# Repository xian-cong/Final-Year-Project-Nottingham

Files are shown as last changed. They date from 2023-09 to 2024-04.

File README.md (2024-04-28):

# WellnessAI+
## Overview of the Project
WellnessAI+ is an intelligent wearable device equipped with electrocardiogram (**ECG**) and advanced **AI** capabilities to offer a groundbreaking approach to **edge computing** to not only **predict heart disease** but also delve into the depths of **human emotions**. In this era of smart wearables, the integration of ECG with AI technology holds the potential to revolutionize the way we understand, monitor, and manage both our physical and emotional well-being. This dual-purpose capability signifies a pivotal leap forward in personalised healthcare and wellness management, ushering in a new era of preventative and predictive medicine.

### Code Directory
- [Obtain Sensor Readings](code/UART_ADC_DMA/CM4/Core/Src/main.c)
- [Emotion Recognition Model](ECG_Emotion_Recognition.ipynb)
- [Data Processing and Feature Extraction](data_preprocessing/printPickleData.py)
- [Running Real Time Inference with STM32MP157F-DK2 and ECG](code/EMOTION_AI/CM4/Core/Src/main.c)

### Demo
#### UI
UI Video (https://www.youtube.com/watch?v=PTiqgje0Kdc)
#### Performance
Demo Video (https://www.youtube.com/watch?v=h7NpJMywoSw)

### Features
- **ECG Monitoring**: The ECG sensor is used to measure the electrical activity of the heart and display the ECG waveform on the screen. The ECG waveform is also sent to the cloud for further analysis.
- **Heart Disease Prediction**: The ECG waveform is sent to the cloud for further analysis. The cloud will then predict the possibility of heart disease based on the ECG waveform. (Future Improvements)
- **Emotion Recognition**: The ECG waveform is sent to the edge for further analysis. The edge will then predict the real-time emotion of the user based on the ECG waveform.

### Design
| Front | Back | Inside | Side |
| :---: | :---: | :---: | :---: |
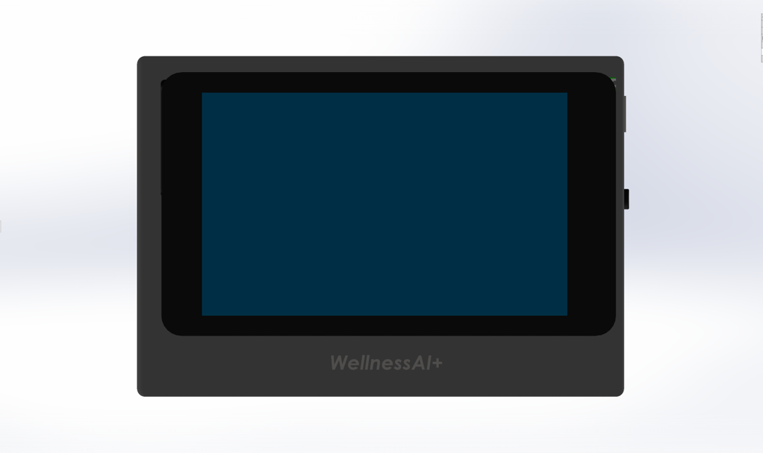
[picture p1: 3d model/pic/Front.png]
front
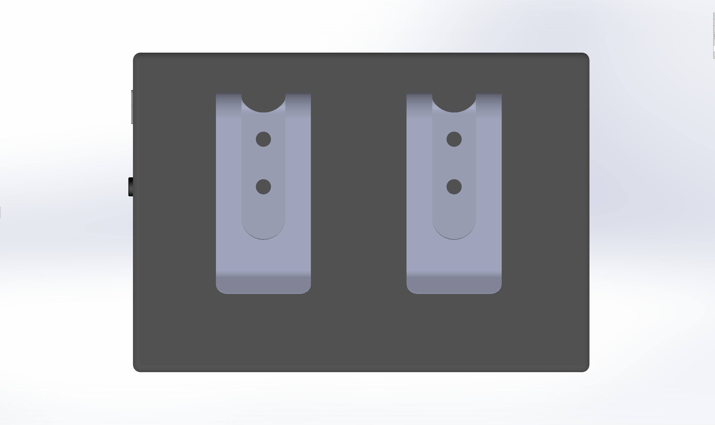
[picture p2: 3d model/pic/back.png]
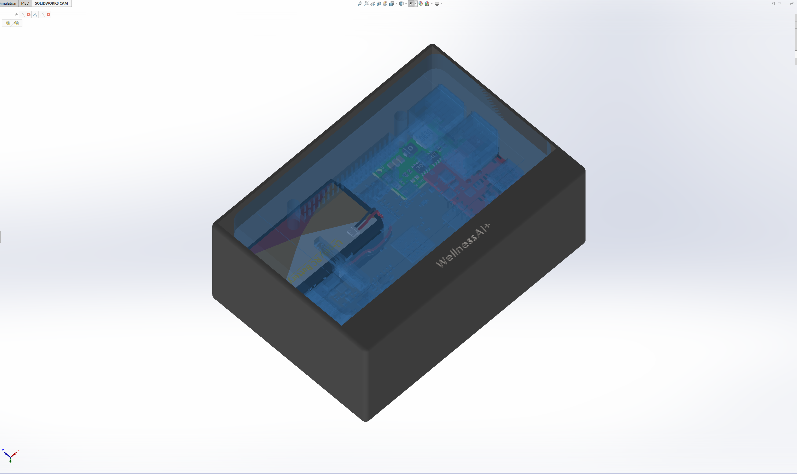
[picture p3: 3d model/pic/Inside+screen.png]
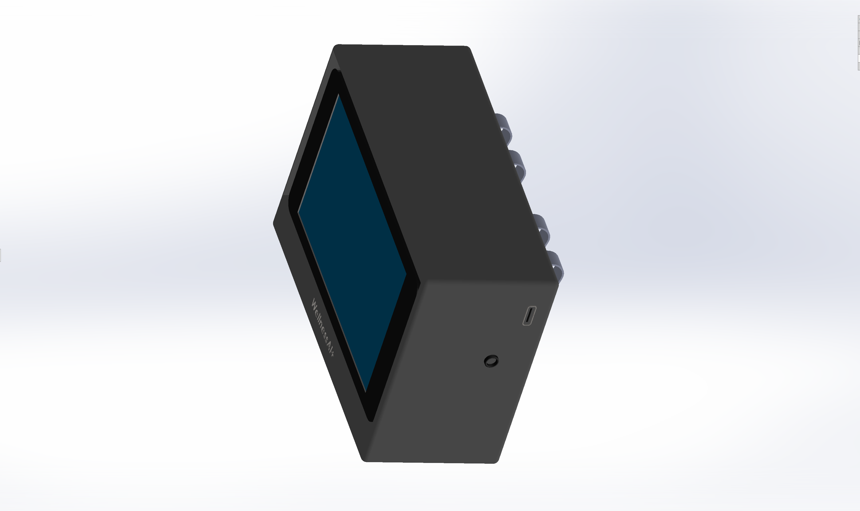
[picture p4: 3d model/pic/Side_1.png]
| |  |  |  

### Tools and Technologies Used
Block Diagram

## System Requirements
### Hardware
- STM32MP157F-DK2
- ECG Measurement Kit

### Software
- STM32CubeIDE (ver. 1.14.1)
- STM32 X-Cube-AI (ver. 8.1.0)
- Python

## Getting Started
### Clone Project
```
git clone https://github.com/xian-cong/Final-Year-Project-Nottingham.git
```

### Install Dependencies
```
pip install -r requirements.txt
```

### Run the Program
```
conda activate fyp_venv
python3 main.py
```

### Hardware Setup
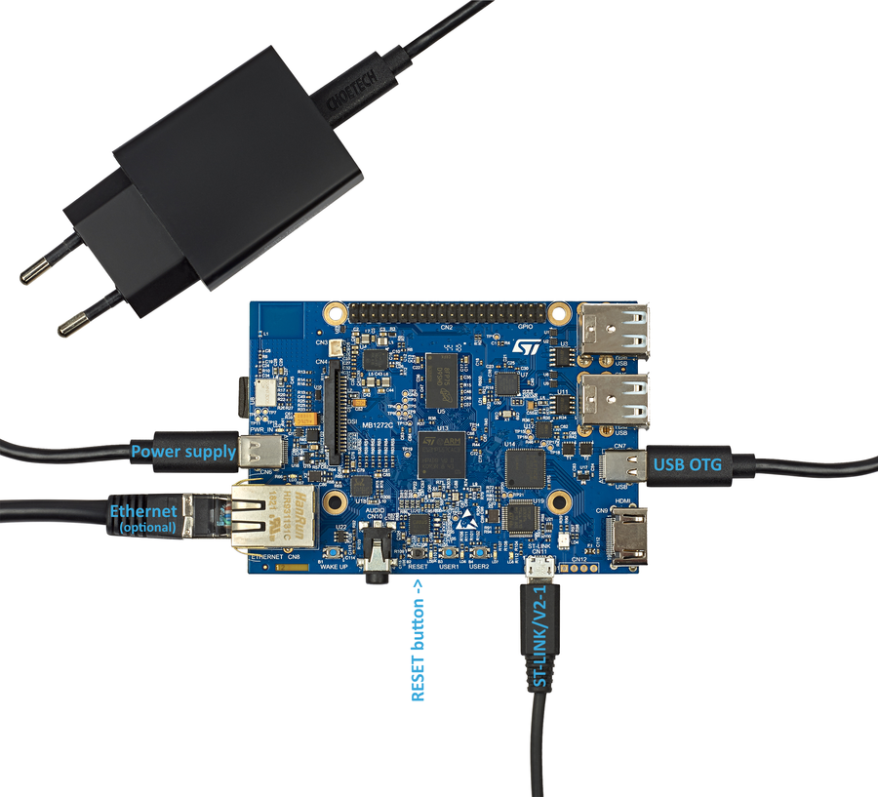
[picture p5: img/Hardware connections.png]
Hardware Setup


### Sensor Connection
Sensor Connection

## Time Management
### Gantt Chart
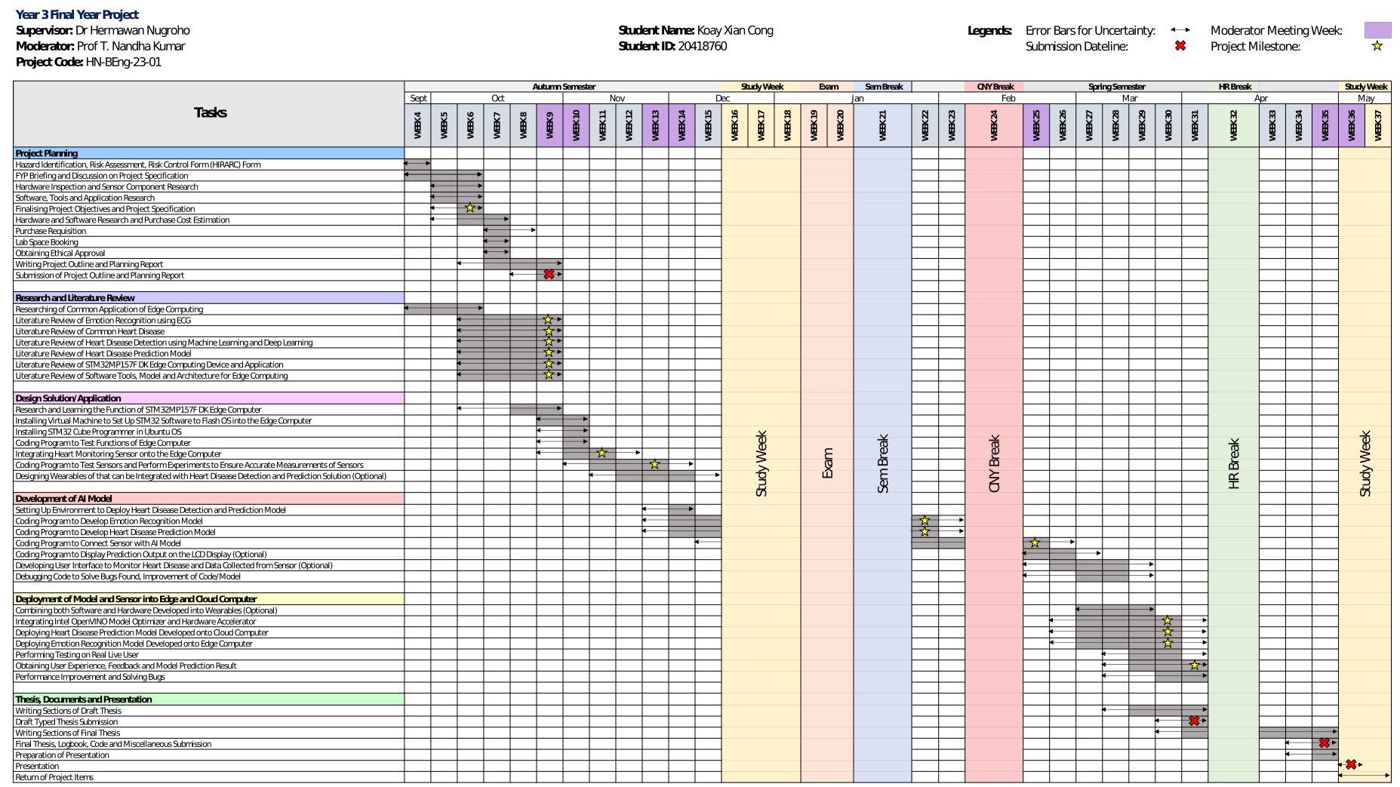
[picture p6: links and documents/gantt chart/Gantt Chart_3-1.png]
Gantt Chart


## Project Documentation
### Project Outline and Planning Report
[Project Proposal](links%20and%20documents/project%20outline%20and%20planning%20report/Project%20Outline%20and%20Planning%20Report.pdf)

### Project Specification
[Project Report](links%20and%20documents/FYP%20Project%20Specification.pdf)

### Project Thesis
[Project Thesis](links%20and%20documents/thesis/20418760%20-%20Koay%20Xian%20Cong%20-%20BEng%20FYP%20Final%20Thesis.pdf)

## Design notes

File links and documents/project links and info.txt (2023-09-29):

1. Intel OpenVino
https://www.intel.com/content/www/us/en/developer/tools/openvino-toolkit/overview.html
An open source toolkit that makes it easier to write once, deploy anywhere.

2. STM32
https://wiki.stmicroelectronics.cn/stm32mcu/wiki/AI:Introduction_to_Artificial_Intelligence_with_STM32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
Description for AI on the edge.

3. ARM Cortex-M
https://developer.arm.com/Architectures/M-Profile%20Architecture
Able to deploy AI using edge computing.

4. ARM Cortex-A
https://en.wikipedia.org/wiki/ARM_Cortex-A
Typical ways to deploy AI.

5. STM32 MPU
https://www.st.com/en/embedded-software/x-linux-ai.html
Able to run Tensorflow Lite and perform computer vision tasks.

6. STM32 Discovery Kit
https://www.st.com/en/evaluation-tools/stm32mp157c-dk2.html
Board that will be used.

7. Heart disease AI developed by previous year students.
https://link.springer.com/chapter/10.1007/978-981-19-3923-5_58
Thesis written.

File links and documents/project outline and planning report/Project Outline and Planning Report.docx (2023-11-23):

The University of Nottingham

Faculty of Engineering

Department of Electrical and Electronic Engineering

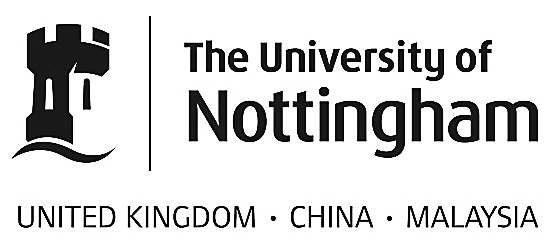
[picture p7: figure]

EEEE3026

Project Outline and Planning Report

WellnessAI+: Elevating Mental, Emotional and Physical Health with ECG-Enhanced Artificial intelligence

AUTHOR : KOAY XIAN CONG

ID : 20418760

SUPERVISOR : DR HERMAWAN NUGROHO

MODERATOR : PROF T. NANDHA KUMAR

DATE : 30th OCT 2023

Contents

# 1. Overview of the Project

Introduction

The focus of this project is to incorporate electrocardiogram (ECG) and artificial intelligence (AI) driven algorithms to offer a groundbreaking approach to edge computing to not only predict heart disease but also delve into the depths of human emotions. In this era of smart wearables, the integration of ECG with AI technology holds the potential to revolutionize the way we understand, monitor, and manage both our physical and emotional well-being. This dual-purpose capability signifies a pivotal leap forward in personalised healthcare and wellness management, ushering in a new era of preventative and predictive medicine. The deployment of AI into edge computers powered by ARM Cortex-M chips will also be further explored and discussed.

Problem Statement

Latterly, there has been growing acknowledgement of the significant impact that mental health has on the attainment of global development objectives, which has been illustrated by the incorporation of the Sustainable Development Goals. According to the World Health Organization (WHO), depression stands out as a major contributor to disability, while suicide ranks fourth leading cause of death among individuals aged 15 to 29. [1] Although there have been advancements made towards mental health issues, individuals dealing with mental health issues frequently encounter serious infringements of their human rights, discrimination, and social stigma. [1]

An electroencephalogram (EEG) is a commonly utilized tool to diagnose and measure the electrical activity in the brain. It involves the use of electrodes placed on the scalp to detect and monitor the brain’s electrical impulses and patterns of activity. The resulting data is typically displayed as a series of waveforms and is used to assess brain function, diagnose various neurological conditions, and study brain activity in research settings. EEGs are commonly employed in clinical medicine to aid in the diagnosis and management of conditions such as epilepsy, seizure disorders, emotions, stress levels, etc. Since EEG is a valuable tool, there are a lot of researchers incorporating EEG as a reliable tool to detect and recognize emotion. However, since EEG electrodes need to have good contact with the scalp to capture accurate brainwave data, achieving consistent and reliable contact with the scalp is difficult in a wearable form factor. Movements and shifts in the device, as well as hair interference, can affect the quality of EEG signals. EEG devices may be uncomfortable, inconvenient and expensive for regular use. [2]

Mental health aside, cardiovascular disease (CVDs) stands as the primary global cause of mortality, claiming around 17.9 million lives annually according to WHO. [3] More than 80% of CVD-related deaths result from heart attacks and strokes, with one-third occurring prematurely in individuals under 70 years of age. [3]

An electrocardiogram (ECG) can perform a simple test that records the electrical activity of the heart over a period. It is a widely used diagnostic tool to assess the heart’s rhythm and electrical conduction. The test is typically performed using electrodes placed on the skin’s surface at specific locations on the chest, arms, and legs. These electrodes detect the electrical signals generated by the heart as it beats and transmit the information to an ECG sensor, which then produces a visual representation of the heart’s electrical activity in the form of a graph or a series of waves. ECG can provide vital information about various aspects of cardiac health, including heart rate, the regularity of heartbeats, signs of abnormal rhythms, and the presence of certain heart conditions, such as ischemia or structural abnormalities. [4] Since ECG is a valuable tool used for diagnosing and monitoring heart-related issues and is commonly used in medical settings, there is a wide array of studies performed on enhancing ECG with Artificial Intelligence on heart disease analysis and prediction.

Background Information

Electrocardiogram (ECG)

An ECG is utilized as a medical test instrument that measures and records the electrical activity of the heart over a period. It provides medical professionals with several vital purposes such as diagnosing heart conditions, monitoring heart issues, etc. A sample signal of the ECG wave is shown in Figure 1. The P-wave represents the electrical signal when the atria contract and push blood into the ventricles. [5] The inter-beat interval (IBI) is used for detecting heart rate, which can be computed based on the distance between R peaks in the ECG waveforms. [6] The QRS complex shows the electrical activity when the ventricles contract to pump blood out to the body. [5] Finally, the T-wave is the recovery phase when the heart’s electrical system gets ready for the next beat. The standard placement of ECG is shown in Figure 2.

Autonomic Innervation of the Heart

According to Anatomy and Physiology 2, there are physiological interrelations between the heart and brain. [7] The autonomic innervation of the heart is a crucial part of the Autonomic Nervous System (ANS), which regulates involuntary bodily functions, including heart rate, blood pressure and respiratory rate. The regulation of heart rate is centred in the paired cardiovascular control centres within the medulla oblongata of the nervous system which are the sympathetic nervous system and the parasympathetic nervous system as shown in Figure 3. [7] While at rest, both centres offer subtle stimulation to the heart, contributing to the autonomic tone. The cardio accelerator triggers the release of the neurotransmitter norepinephrine, leading to a significant rise in heart rate, which takes place in both the sympathetic nervous system (SNS) and the sinoatrial (SA) node, while the cardioinhibitory release the neurotransmitter acetylcholine (Ach) into the parasympathetic nervous system (PNS). [7] The ANS would react based on the situation and alterations in the emotional experiences. For instance, a cardioaccelerator will be triggered in a “flight-or-fight” situation [8] whenever a person is in danger. Thus, when emotions are experienced, this interaction between the heart and brain can lead to certain changes or variations in how those emotions are felt or expressed. Hence, emotional experiences are not only influenced by our thoughts and feelings but also by the physiological interplay between heart and brain.

Arrhythmia

As discussed in the problem statement, CVDs contribute a significant amount of mortality. One of the approaches to detect arrhythmia is to use ECG. [9] Arrhythmia refers to an irregular or abnormal heartbeat. [10] The heart typically beats in a regular, rhythmic pattern to pump blood throughout the body which can be shown in the ECG waveform in Figure 1. In instances of arrhythmia, the heart can exhibit deviations in its rhythm, which may denote as excessive speed, rhythm or irregular pattern. [11] The severity of this condition varies, ranging from benign to life-threatening, depending on its specific type and its impact on an individual’s overall well-being. Arrhythmias may lead to symptoms such as palpitations, dizziness, breathlessness, or chest discomfort. [12] Thus, accurate diagnosis and monitoring of arrhythmias are essential to maintain good heart health.

Consumer Demand

To develop a wearable that can perform real-time emotion recognition on the edge as well as perform heart disease prediction on the cloud, the system needs to be accurate and lightweight. [5] Moreover, as stated in the problem statement, both mental and physical health contributed a significant amount of mortality based on statistics given by WHO. Based on a national survey performed in the US, roughly 30% of American adults make use of healthcare wearable devices. [13] Among these users, about 47.33% use these devices daily, and a significant majority, representing 82.38%, express their willingness to share the health data collected from these wearables with their healthcare providers, emphasizing the potential for healthcare professionals to access vital information for better-informed medical decisions. [13] Thus, based on the potential number of users available, it reveals a compelling case for the development and commercialization of healthcare wearables which ultimately enhance the overall quality of healthcare services.

Aim

The objective of this project is to create a health monitoring system that integrates an ECG measurement kit with an STM32 edge computer and a cloud-based computer. This system comprises two key components: a model for predicting heart disease (cloud computer) and another for real-time emotion recognition (edge computer). The most important goal is to design a circuit that captures bioelectric signals from the heart accurately. Next, a data processing method to acquire features with physiological and physical significance needs to be designed. [2] This innovative approach allows users to not only track their physical health but also their mental well-being. Additionally, the project explores the utilization of Intel OpenVINO as a model optimizer and hardware accelerator, facilitating the deployment of AI models without the need to modify the underlying code. The model for real-time emotion recognition needs to be lightweight enough to be embedded into a device to implement edge computing. [2] [5]

This project holds significant importance in the realm of healthcare technology. Combining ECG measurement with advanced AI models, it offers a holistic approach to health monitoring, addressing both physical and emotional aspects. The ability to predict heart disease can lead to early intervention and potentially life-saving measures. Real-time emotion recognition can aid in mental health support, especially in times when stress and emotional well-being are increasingly critical. The use of Intel OpenVINO streamlines the deployment of AI models, making this technology more accessible and adaptable for a wide range of applications.

Block Diagram

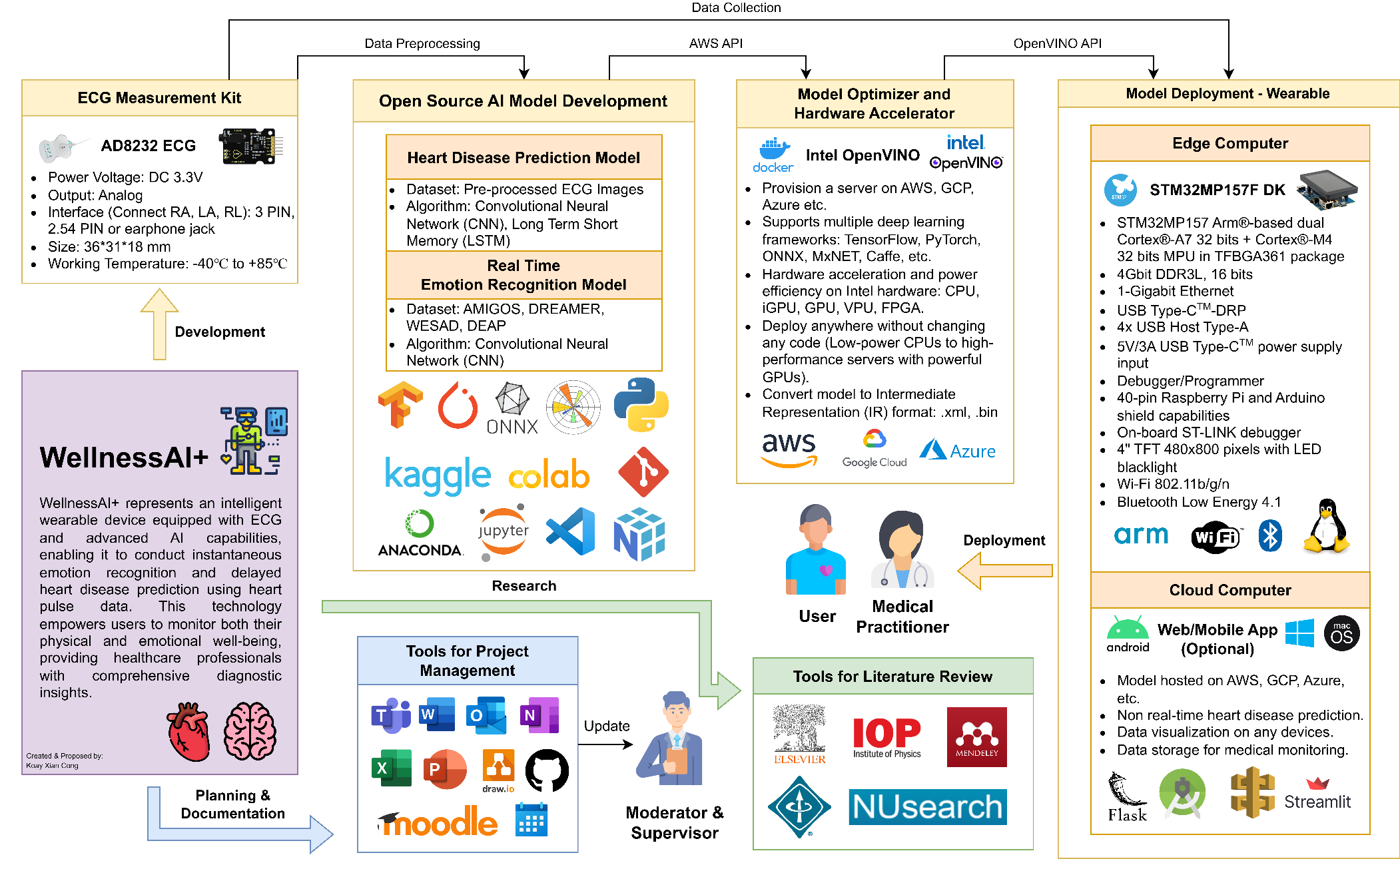
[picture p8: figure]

# 2. Specification

Hardware

Requirements: Setting up STM32MP157F DK edge computer.

Priority: High

Standards & Practices: Follow the manufacturer’s guidelines or hardware setup and ensure electrical safety protocols. [14]

Tests:

1. Conduct a power-on test.
2. Validate hardware connections.
3. Verify the functionality of essential components.

Success Measure: Successful boot-up and initialization of STM32MP157F DK with no hardware and electrical issues.

Attainability and Achievability: Achievable with the necessary resources and adherence to the manufacturer's instructions. [14]

Requirements: Integrating ECG measurement kit onto edge computer.

Priority: High

Standards & Practices: Ensure secure and accurate data transmission, and compliance with medical data protection standards.

Tests:

1. Verify data connection between the ECG kit and edge computer.
2. Confirm data accuracy.

Success Measure: Successful integration with consistent, accurate ECG data transmission.

Attainability and Achievability: Achievable with appropriate hardware interfaces and software development.

Requirements: Create a real-life model of the wearable designed to integrate both software and hardware onto it.

Priority: Low (Stretch goal)

Standards & Practices: Utilize ergonomic design to ensure user comfort and safety.

Tests:

1. Conduct usability tests with potential users.
2. Assess integration of hardware and software components into the wearables.

Success Measure: Positive feedback from users on functionality and design.

Attainability and Achievability: Challenging but attainable as a stretch goal, may require additional resources and time.

Software

Requirements: Setting up applications and tools for software development.

Priority: High

Standards, Practices and Licenses: Follow industry best practices, and adhere to software development guidelines and licensing agreements. Use open-source tools and software.

Tests:

1. Ensure proper installation of development tools.
2. Run initial tests to confirm they function as intended.

Success Measure: Successful setup of software development environment without any critical issues.

Attainability and Achievability: Achievable with the necessary software and resources.

Requirements: Coding program to familiarize and test functions of edge computer and ECG.

Priority: Medium

Standards, Practices and Licenses: Adhere to coding and programming best practices, ensure modularity and standardization of code, and follow any relevant licenses for code libraries. Use open-source libraries.

Tests:

1. Run test cases to confirm the functionality of the edge computer and ECG components.

Success Measure: Successful development of a program that effectively tests and familiarizes with edge computer and ECG.

Attainability and Achievability: Achievable with the necessary programming skills and resources.

Requirements: Coding program to test ECG sensor.

Priority: Medium

Standards, Practices and Licenses: Adhere to coding and programming best practices, ensure modularity and standardization of code, and follow any relevant licenses for code libraries. Use open-source libraries.

Tests:

1. Conduct tests and experiments to verify the accuracy and reliability of ECG sensor data.

Success Measure: A program that effectively tests the ECG sensor and provides reliable data.

Attainability and Achievability: Achievable with the necessary programming skills and resources.

Requirements: Designing wearables to integrate edge computer and ECG sensors.

Priority: Low (Stretch goal)

Standards, Practices and Licenses: Follow wearable design best practices, and consider safety and user comfort.

Tests:

1. Conduct usability tests with potential users.
2. Assess integration of hardware and software components into the wearable.

Success Measure: Positive feedback on the design and functionality of the integrated wearable.

Attainability and Achievability: Challenging but attainable as a stretch goal, may require additional design and engineering resources.

Requirements: Coding program to create and test heart disease prediction model.

Priority: High

Standards, Practices and Licenses: Adhere to coding and programming best practices, ensure modularity and standardization of code, and follow any relevant licenses for code libraries. Use open-source libraries and datasets.

Tests:

1. Conduct tests to verify the accuracy and effectiveness of the heart disease prediction model.

Success Measure: A functional program that successfully creates and tests the heart disease prediction model.

Attainability and Achievability: Achievable with the necessary programming skills and resources.

Requirements: Coding program to create and test emotion recognition model.

Priority: High

Standards, Practices and Licenses: Adhere to coding and programming best practices, ensure modularity and standardization of code, and follow any relevant licenses for code libraries. Use open-source libraries and datasets.

Tests:

1. Conduct tests to verify the accuracy and effectiveness of the emotion recognition model.

Success Measure: A functional program that successfully creates and tests the emotion recognition model.

Attainability and Achievability: Achievable with the necessary programming skills and resources.

Requirements: Implementing Intel OpenVINO as a model optimizer and hardware accelerator.

Priority: Medium

Standards, Practices and Licenses: Follow the manufacturer’s guidelines, and comply with relevant licensing agreements.

Tests:

1. Validate the performance improvement achieved through OpenVINO optimization.

Success Measure: Successful integration and performance improvement using Intel OpenVINO.

Attainability and Achievability: Achievable with access to OpenVINO resources and appropriate hardware.

Requirements: Setting up and deployment of heart disease prediction model in cloud computer.

Priority: Medium

Standards, Practices and Licenses: Ensure cloud deployment adheres to security and privacy standards and complies with licensing agreements.

Tests:

1. Validate the successful deployment and functioning of the heart disease prediction model in the cloud.

Success Measure: Successful deployment of the model in the cloud environment with proper functionality.

Attainability and Achievability: Achievable with access to cloud computing resources and expertise.

Requirements: Deployment of emotion recognition model in edge computer.

Priority: Medium

Standards, Practices and Licenses: Ensure compliance with edge computing best practices and relevant licenses.

Tests:

1. Confirm that the emotion recognition model works effectively on the edge computer.

Success Measure: Successful deployment of the model on the edge device with proper functionality.

Attainability and Achievability: Achievable with the necessary edge computing resources and expertise.

Requirements: Coding program to display data collected from sensor and model output result.

Priority: Low (Stretch goal)

Standards, Practices and Licenses: Follow best practices for data visualization and ensure compliance with relevant licenses. Use open-source libraries.

Tests:

1. Validate the program’s ability to display sensor data and model output results effectively.

Success Measure: Development of a program that successfully displays sensor data and model output results.

Attainability and Achievability: Achievable as a stretch goal, may require additional software development resources.

# 3. Methodology

Step 1: Setting up software and hardware for STM32MP157F-DK2.

Relevant tools, Justification & Limitations:

1. STM32MP157F-DK2. [14]
- Powerful hardware: Powered by a dual-core ARM Cortex-A7 CPU with an ARM Cortex-M4 microcontroller, it is power-efficient and suitable for real-time tasks.
- Power efficiency: STM32MP1 microprocessors are designed for low power consumption, making them well-suited for battery-powered or wearable devices.
- Real-time capabilities: The presence of an ARM Cortex-M4 microcontroller on the edge computer allows for real-time control and signal processing, which can be crucial for the deployment of real-time emotion recognition.
- Customization: Comes with a 4” TFT 480x800 pixels with LED backlight, allowing data collected and model output to be displayed.

Limitations:

- Compared to Raspberry Pi, STM32MP157F-DK2 has fewer readily available resources and support due to smaller communities.
- STM32MP157D-DK2 is less common and requires sourcing from specific distributors.
2. VirtualBox to run Ubuntu OS.
- Compatibility: The STM32 Cube Programmer has better compatibility with a Linux environment since the documentation given is in Ubuntu OS. This ensures that it functions smoothly without any compatibility issues.

Limitations:

- Virtualization introduces overhead, which can impact the overall performance of running STM32 Cube Programmer and other applications.
- USB passthrough may not work seamlessly with all STM32 devices or programming and debugging tools.
- The STM32 Cube Programmer relies on USB drivers and hardware communication. Virtualized environments can sometimes be less compatible with specialized drivers, leading to connectivity and communication problems with STM32 devices.
3. STM32 Cube programmer. [14]
- Official tool by STMicroelectronics: STM32 Cube Programmer is developed and maintained by the manufacturer, ensuring compatibility and reliability.
- Integrated Development Environment: STM32 Cube Programmer is part of the STM32Cube ecosystem, which provides a comprehensive set of development tools for STM32 microcontrollers and microprocessors. It integrates well with other STM32Cube tools and libraries, streamlining the development process.
- Programming and debugging: It offers a user-friendly interface for programming STM32 devices, which can include flashing firmware, configuring settings, memory management, and debugging applications.

Limitations:

- STM32 Cube Programmer can be resource-intensive, particularly when working with large projects.

Potential Additional Tasks: Familiarize with Ubuntu OS and STM32 Cube programmer.

Step 2: Integrating ECG kit onto edge computer.

Relevant tools, Justification & Limitations:

1. AD8232 ECG measurement kit. [15]
- Data collection: The ECG measurement kit is chosen for its accuracy and precision in collecting vital heart activity.

Limitations:

- Ensuring seamless compatibility between the ECG kit into the edge computer may be technically challenging and may require expertise in hardware interfacing.
- Wearable ECG sensors may not be as comfortable for long-term use, potentially affecting user adoption and compliance.

Potential Additional Tasks:

- Perform tests and experiments to verify that the ECG kit is functioning correctly and can collect ECG data accurately.
- Implementation of data transmission protocols to ensure that ECG data collected by the kit can be transmitted to the edge computer in real time.

Step 3: Open-Source AI Model Development.

Relevant tools, Justification & Limitations:

1. Python and machine learning (ML)/deep learning (DL) libraries (NumPy, Matplotlib, etc.).
- Open source: Python is a widely used programming language for ML and DL. It has various libraries available for data manipulation, analysis, visualization, etc in AI model development.

Limitations:

- Advanced DL models may require substantial computational resources, which could impact performance on resource-constraints systems.
2. Anaconda/Google Colab.
- Local training: Anaconda provides a convenient environment for managing Python packages and creating isolated development environments. Since there are 2 models developed: heart disease prediction and emotion recognition, this feature ensures package compatibility between projects.
- Cloud training: Google Colab is a cloud-based platform that offers free GPU and TPU resources for training DL models, reducing the need for computational power.

Limitations:

- The availability of free resources on Google Colab may be limited, and reliance on cloud-based resources may have data privacy and internet connectivity considerations. Running DL models locally requires a lot of computational power and time.
3. Deep learning libraries (TensorFlow/PyTorch, etc.).
- Pre-built neural network architectures: Enabling AI model development more accessible and efficient with optimization tools and GPU acceleration available.

Limitations:

- Implementing complex neural network architecture requires expertise in DL, and training large models may demand significant computational resources.
4. Git/GitHub.
- Efficient: Version control system that allows for efficient version tracking in AI model development.

Limitations:

- Managing large datasets or models within Git repositories can be challenging, and it’s important to follow best practices to avoid repository bloat.

Potential Additional Tasks:

- Familiarize with software tools and DL models.
- Perform data preprocessing, which may involve tasks like data augmentation, normalization, and feature extraction, to prepare the input data for the AI model.
- Retrain model available online to validate the accuracy and performance of the model.

Step 4: Model Optimizer and Hardware Accelerator.

Relevant tools, Justification & Limitations:

1. Intel OpenVINO Toolkit.
- Compatibility: Supports multiple DL frameworks (TensorFlow, PyTorch, etc.).
- Performance: Enhance the performance and efficiency of AI models, allowing them to run seamlessly on Intel-based hardware.
- Code reusability: Deploy anywhere without changing any code.

Limitations:

- Depending on the complexity of the AI models and the specific hardware accelerators used, there may be some steep learning curve and resource req to effectively utilize the Intel OpenVINO Toolkit.

Additional Tasks:

- Familiarize with Intel OpenVINO Toolkit.
- Configure and optimize AI models using the Intel OpenVINO Toolkit for deployment on the STM32MP57F-DK2 hardware accelerator and assess the performance improvements achieved through model optimization.

Step 5: Deployment of AI models into edge computers and cloud computers.

Relevant tools, Justification & Limitations:

1. Edge Computer (STM32MP157F).
- As discussed above.
2. Cloud Computer (AWS, Azure, GCP).
- Scalable resources: Cloud platforms offer scalable compute resources, allowing for the deployment of large and complex AI models.
- High-performance GPU: Cloud providers often offer access to powerful GPU instances, which can significantly accelerate AI model inference and training.
- Deployment into Web/Mobile apps: Cloud providers offer APIs to link the results onto frontend web/mobile apps.

Limitations:

- AI models deployed in the cloud may experience network latency, which can be a concern for real-time applications.
- AI models deployed in the cloud may experience network latency, which can be a concern for real-time applications.

Potential Additional Tasks:

- Ensure that the AI models are optimized for deployment on both the edge computer and the cloud platform.

# 4. Risk Management and Mitigations

Step 1: Setting up software and hardware for STM32MP157F-DK2.

1. Risk: Limited Community Support: Difficult to get support when issues arise.

Mitigation: Establish direct contact with STM32MP157F-DK2 user forums, seek expert advice, and build a network of contacts for troubleshooting.

Impact: Limited community support may result in longer issue resolution times.

Likelihood: Medium

2. Risk: Hardware Compatibility: Incompatibility issues between the STM32MP157F-DK2 and the ECG measurement kit may arise.

Mitigation: Prior to integration, perform compatibility testing, and refer to hardware documentation.

Impact: Delay in project timeline.

Likelihood: Low

3. Risk: Human error: Short circuit due to incorrect power connections.

Mitigation: Supply power and connect peripherals to the edge computer by adhering to the documentation and requirements.

Impact: Delay in project timeline if new microcontroller order is needed.

Likelihood: Low

Step 2: Integrating ECG kit onto edge computer.

1. Risk: Health and safety issue: ECG sensor being tested on real-life human needs to adhere to health and safety compliance.

Mitigation: The subject’s skin needs to be wiped with alcohol before snap on electrode is applied. [2]

Impact: Health and safety issues can lead to ethical and legal concerns, project delays, and potential health risks to human subjects.

Likelihood: High

Step 3: Open-Source AI Model Development

1. Risk: Computational Resources: Advanced deep learning models may require substantial computational resources, impacting project performance on resource-constrained systems.

Mitigation: Optimize and simplify AI models, employ cloud-based resources when necessary, and manage hardware efficiently.

Impact: Delayed model training, and performance degradation.

Likelihood: High

2. Risk: Data Privacy: Reliance on cloud-based resources may raise security concerns.

Mitigation: Implement data encryption, access control, and ensure compliance with data protection regulations. Use open-source datasets.

Impact: Data breaches, legal liabilities.

Likelihood: High

3. Risk: Model detection: An exclusive reliance on deep learning methods proved insufficient in identifying all crucial ECG signal features. [5] [11]

Mitigation: Hybrid strategy is applied to improve detection efficiency. [5]

Impact: Inefficient model detection can lead to inaccurate results and potentially harmful misdiagnoses.

Likelihood: High

4. Risk: Dataset Requirement: ECG signal analysis demands a substantial volume of data for accurate results, increasing the risk of misdiagnosing specific heart conditions. [11]

Mitigation: Adequately address data volume requirements by ensuring the dataset size is sufficient for the AI models' training and validation processes. Performing data augmentation to increase the size of the dataset available.

Impact: Inadequate data volume can lead to misdiagnoses and reduce the AI model's effectiveness.

Likelihood: High

5. Risk: Dataset Availability: Discovering a comprehensive framework with corresponding standards accessible to the general population is a complex task. [11]

Mitigation: Explore various sources, including open-source datasets to gather a diverse and representative ECG dataset. Ensure compliance with data protection regulations.

Impact: Limited or inadequate dataset availability can hinder AI model development and testing.

Likelihood: High

6. Risk: Human factors: Age, gender, physical health, and lifestyle exert an influence on the amplitude and duration of individuals' ECG readings. [11]

Mitigation: Focus on a specific group of users and reduce the range of demographic groups.

Impact: Failure to account for human factors can lead to biased or unreliable AI models.

Likelihood: Medium

7. Risk: Wearable deployments: Physical activity, such as running, walking, and sleeping can affect the ECG signal’s morphology, contributing to signal noise. [11]

Mitigation: Develop noise-filtering algorithms and signal-preprocessing techniques to enhance the quality of ECG data collected from wearable devices.

Impact: Failure to address signal noise can lead to inaccurate ECG signal analysis.

Likelihood: Medium

Step 4: Model Optimizer and Hardware Accelerator

1. Risk: Learning Curve: Utilizing the Intel OpenVINO Toolkit effectively may require a steep learning curve.

Mitigation: Invest time in training and tutorials, seek expert assistance, and start with smaller, well-documented models.

Impact: Delays in model optimization, increased development time.

Likelihood: Medium

2. Risk: Resource Requirements: Depending on the complexity of AI models and the specific hardware accelerators used, resource requirements may be higher than anticipated.

Mitigation: Conduct thorough resource planning, allocate sufficient resources, and monitor utilization.

Impact: Performance bottlenecks, potential project overruns.

Likelihood: Medium

Step 5: Deployment of AI models into edge computer and cloud computer

1. Risk: Real-Time Edge Deployment Challenges: The model takes too long to produce output.

Mitigation: Rigorously test AI model deployment on the STM32MP157F-DK2 to ensure real-time performance and functionality.

Impact: Real-time deployment issues can lead to model inaccuracies and reduced usability.

Likelihood: High

2. Risk: API and Compatibility Challenges: AI models developed are difficult to implement into edge and cloud computers due to API and compatibility issues.

Mitigation: Perform test cases with available AI models before training a new model.

Impact: Delay in project timeline.

Likelihood: High

3. Risk: Network Latency: AI models deployed in the cloud may experience network latency.

Mitigation: Optimize model size, employ edge computing where possible, and implement network performance enhancements.

Impact: Delayed response times.

Likelihood: Medium

4. Risk: User comfort in wearable deployments: Wearable ECG sensors may not be comfortable for extended use, potentially impacting user compliance.

Mitigation: Conduct user testing, gather feedback, and refine the design to enhance user comfort.

Impact: Reduced user adoption, less reliable data.

Likelihood: Medium

5. Risk: Cost Overruns: Cloud-based deployment can incur unexpected costs, especially for resource-intensive AI models.

Mitigation: Implement cost monitoring and budgeting, choose cost-efficient configurations, and regularly review usage.

Impact: Exceeding budget, financial strain.

Likelihood: Low

# 5. Time Plan

The Gantt Chart for time planning has been structured considering the interdependencies between tasks. It consists of six primary tasks scheduled chronologically, which include:

1. Project planning,
2. Research and literature review,
3. Design solutions/applications,
4. Development of AI model,
5. Deployment of model and sensor into edge and cloud computer,
6. Thesis, documents and presentation.

Within the "Design solutions/applications" phase, there's a requirement to set up and test ECG sensors, STM32MP157F, and software. This precedes the design of the model architecture before moving on to the development of the AI model. The deployment of the model and sensor hinges on the completion of the AI model, so it follows this phase.

To ensure tasks stay on track, there are project milestones marked at various points, and four progress reviews are scheduled:

1. Moderator Review 1 (Week 9 – Week 10):
- Finalising Project Objectives and Project Specifications.
- Research and literature review.
2. Moderator Review 2 (Week 13 – Week 14):
- Coding program to test functions of edge computer.
- Coding program to test sensors and perform experiments to ensure accurate measurements of sensors.
3. Moderator Review 3 (Week 25):
- Coding program to develop emotion recognition model.
- Coding program to develop heart disease prediction model.
- Coding program to connect sensor with AI model.
4. Moderator Review 4 (Week 35 – Week 36):
- Integrating Intel OpenVINO model optimizer and hardware accelerator.
- Deploying heart disease prediction model developed onto cloud computer.
- Deploying emotion recognition model developed onto edge computer.
- Obtaining user experience, feedback and model prediction results.

In light of the potential risks and issues mentioned earlier, a parallelization technique is applied to enable the execution of multiple tasks simultaneously, particularly those that are independent of one another.

Additionally, provisions have been made for debugging codes and addressing bugs that may surface during model development and user testing. Improvements can be made based on feedback obtained from users.

The Gantt chart also incorporates error bars to account for uncertainties. In cases where previously unidentified risks arise, these error bars provide additional time to mitigate the issues.

Lastly, the Gantt chart includes optional and supplementary tasks, described as stretch goals, which can be pursued if there is available time before each progress review.

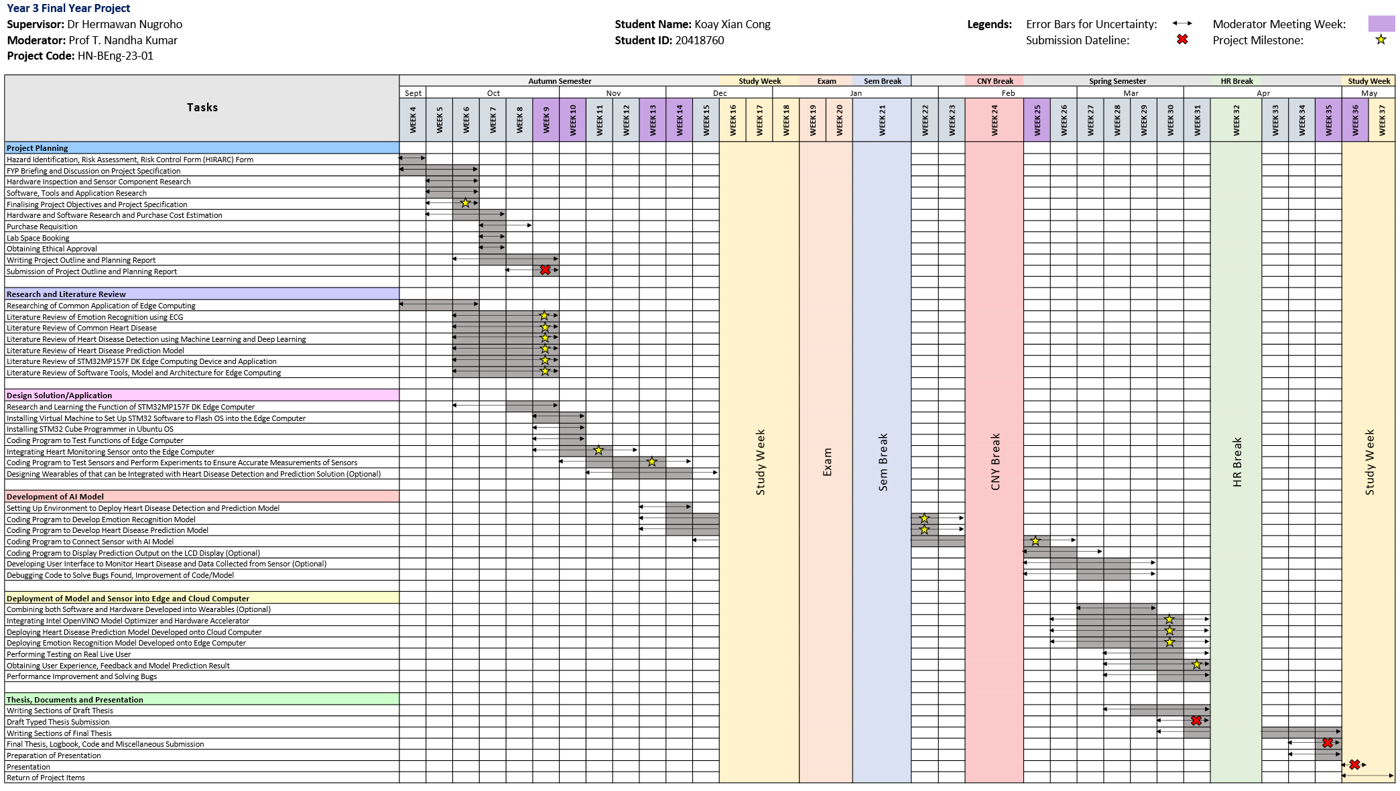
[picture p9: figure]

Gantt Chart

# 6. References

[1] “Mental health.” Accessed: Oct. 19, 2023. [Online]. Available: https://www.who.int/health-topics/mental-health#tab=tab_1

[2] X. Wang, J. Zhang, C. He, H. Wu, and L. Cheng, “A Novel Emotion Recognition Method Based on the Feature Fusion of Single-Lead EEG and ECG Signals,” IEEE Internet Things J, 2023, doi: 10.1109/JIOT.2023.3320269.

[3] “Cardiovascular diseases.” Accessed: Oct. 19, 2023. [Online]. Available: https://www.who.int/health-topics/cardiovascular-diseases#tab=tab_1

[4] Ed Burns and Mike Cadogan, “Myocardial Ischaemia • LITFL • ECG Library Diagnosis.” Accessed: Oct. 19, 2023. [Online]. Available: https://litfl.com/myocardial-ischaemia-ecg-library/

[5] A. L. Golande and T. Pavankumar, “Optical electrocardiogram based heart disease prediction using hybrid deep learning,” J Big Data, vol. 10, no. 1, pp. 139–13, 2023, doi: 10.1186/s40537-023-00820-6.

[6] A. Tjolleng et al., “Classification of a Driver’s cognitive workload levels using artificial neural network on ECG signals,” Appl Ergon, vol. 59, no. Pt A, pp. 326–332, 2017, doi: 10.1016/j.apergo.2016.09.013.

[7] J. G. Betts et al., Anatomy & Physiology -OpenStax. 2013.

[8] P. J. Bota, C. Wang, A. L. N. Fred, and H. Placido Da Silva, “A Review, Current Challenges, and Future Possibilities on Emotion Recognition Using Machine Learning and Physiological Signals,” IEEE access, vol. 7, pp. 140990–141020, 2019, doi: 10.1109/ACCESS.2019.2944001.

[9] H. Yang and Z. Wei, “Arrhythmia Recognition and Classification Using Combined Parametric and Visual Pattern Features of ECG Morphology,” IEEE Access, vol. 8, 2020, doi: 10.1109/ACCESS.2020.2979256.

[10] K. Subramanian and N. K. Prakash, “Machine learning based cardiac arrhythmia detection from ECG signal,” in Proceedings of the 3rd International Conference on Smart Systems and Inventive Technology, ICSSIT 2020, 2020. doi: 10.1109/ICSSIT48917.2020.9214077.

[11] T. Padma, A. Uday Kiran, C. Jahnavi, S. Rahul, N. Raja, and M. Kamal Kumar, “Detection and Classification of Arrhythmias by Deploying Deep Learning Models,” in Journal of Physics: Conference Series, 2022. doi: 10.1088/1742-6596/2325/1/012053.

[12] A. A. Salman and A. Ibarahim, “Detection of Cardiac Arrhythmias in Electroc Ardiograms Using Deep Learning,” in ISMSIT 2022 - 6th International Symposium on Multidisciplinary Studies and Innovative Technologies, Proceedings, 2022. doi: 10.1109/ISMSIT56059.2022.9932742.

[13] R. Chandrasekaran, V. Katthula, and E. Moustakas, “Patterns of Use and Key Predictors for the Use of Wearable Health Care Devices by US Adults: Insights from a National Survey,” Journal of Medical Internet Research, vol. 22, no. 10. 2020. doi: 10.2196/22443.

[14] “Unpack the STM32MP157x-DK2 board - stm32mpu.” Accessed: Oct. 22, 2023. [Online]. Available: https://wiki.st.com/stm32mpu/wiki/Getting_started/STM32MP1_boards/STM32MP157x-DK2/Let%27s_start/Unpack_the_STM32MP157x-DK2_board

[15] “Ks0261 keyestudio AD8232 ECG Measurement Heart Monitor Sensor Module - Keyestudio Wiki.” Accessed: Oct. 22, 2023. [Online]. Available: https://wiki.keyestudio.com/Ks0261_keyestudio_AD8232_ECG_Measurement_Heart_Monitor_Sensor_Module#Test_Result

[16] J. Gordon Betts et al., Anatomy and Physiology 2e. Houston, Texas: OpenStax, 2022.

# 7. Appendix

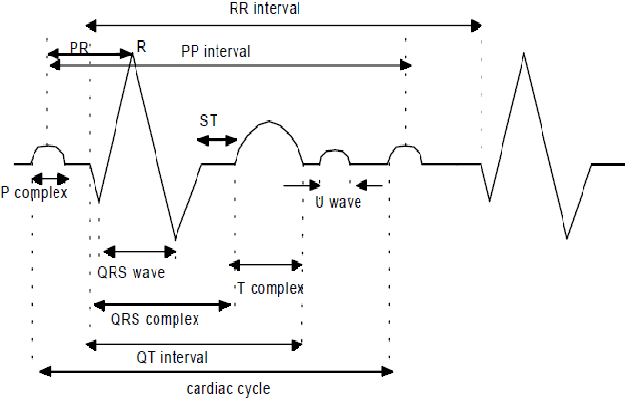
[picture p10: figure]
Figure 1 from Fig : A cardiac cycle of an ECG Classification of Arrhythmia | Semantic Scholar

Figure 1. EEG cycle.

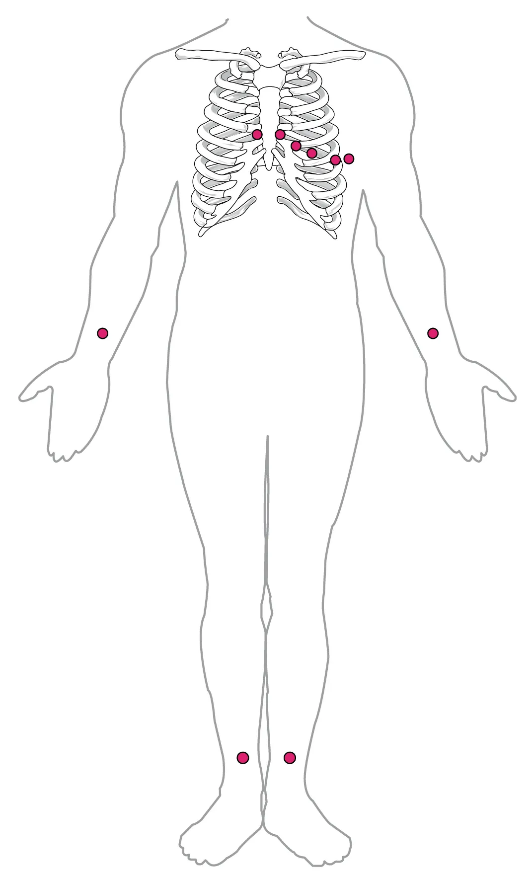
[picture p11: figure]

Figure 2. Standard placement of ECG. [16]

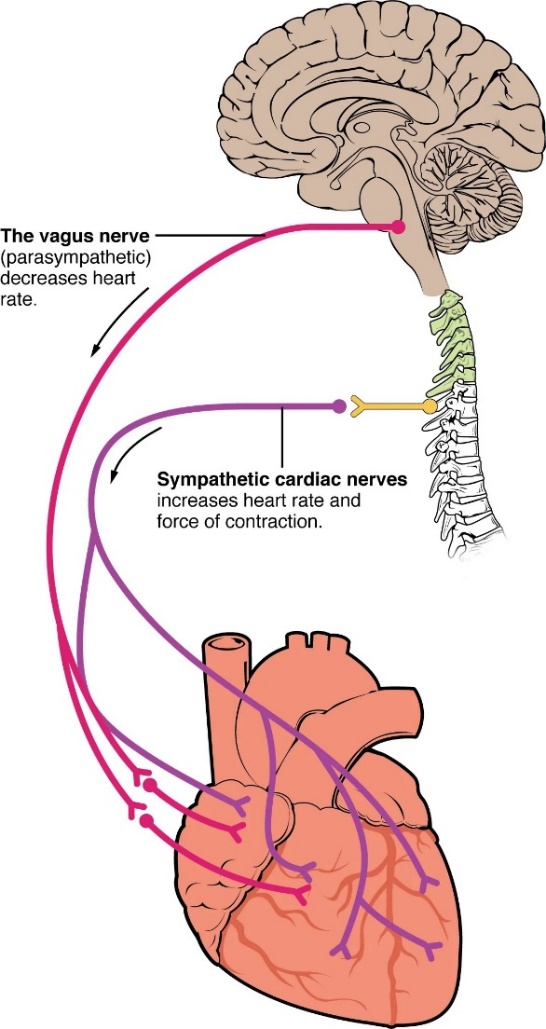
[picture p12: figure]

Figure 3. Autonomic Innervation of the Heart.

Project Specifications

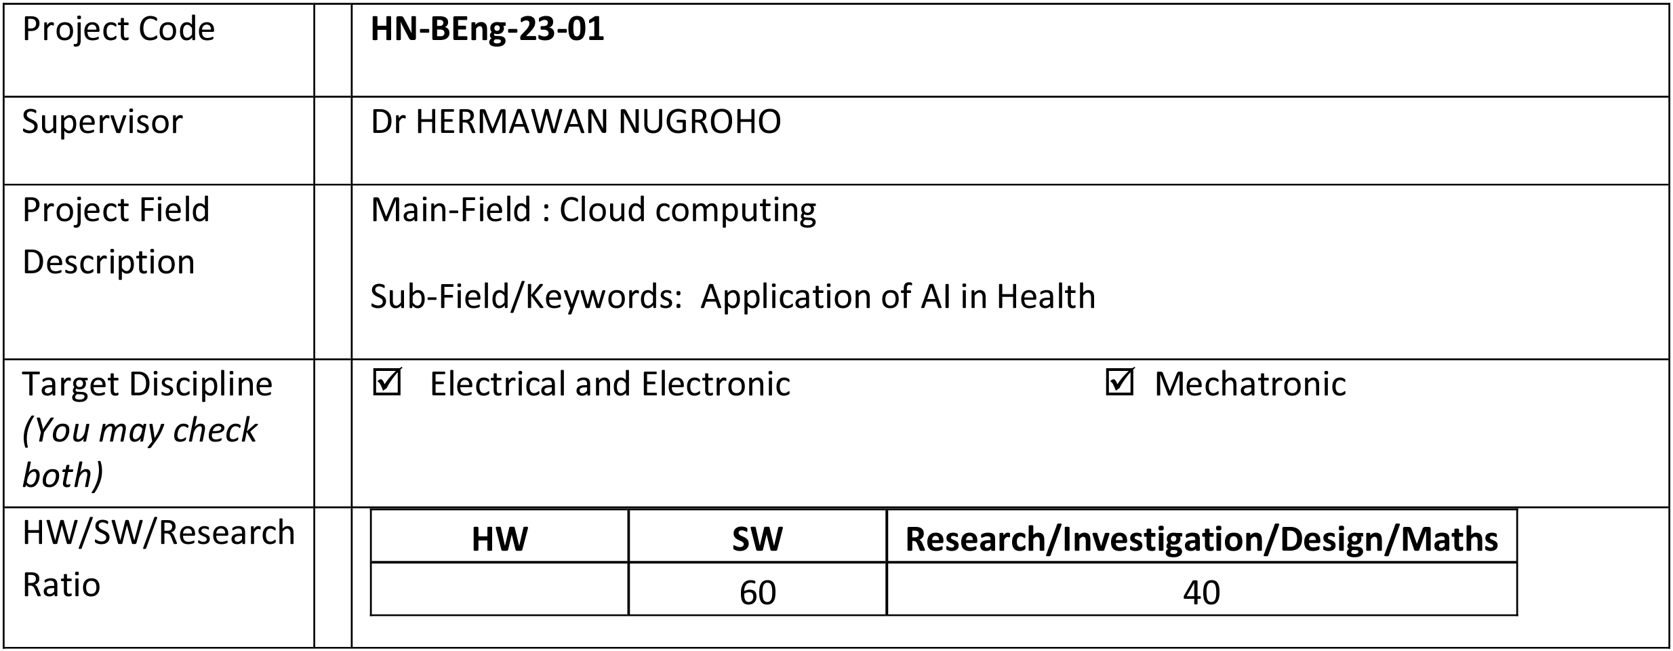
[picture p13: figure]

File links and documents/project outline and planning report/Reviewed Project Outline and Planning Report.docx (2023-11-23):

The University of Nottingham

Faculty of Engineering

Department of Electrical and Electronic Engineering


EEEE3026

Project Outline and Planning Report

WellnessAI+: Elevating Mental, Emotional and Physical Health with ECG-Enhanced Artificial intelligence

AUTHOR : KOAY XIAN CONG

ID : 20418760

SUPERVISOR : DR HERMAWAN NUGROHO

MODERATOR : PROF T. NANDHA KUMAR

DATE : 30th OCT 2023

Contents

# 1. Overview of the Project

Introduction

The focus of this project is to incorporate electrocardiogram (ECG) and artificial intelligence (AI) driven algorithms to offer a groundbreaking approach to edge computing to not only predict heart disease but also delve into the depths of human emotions. This dual-purpose capability signifies a pivotal leap forward in personalized healthcare and wellness management, ushering in a new era of preventative and predictive medicine. The deployment of AI into edge computers powered by ARM Cortex-M chips will also be further explored and discussed.

Problem Statement

According to the World Health Organization (WHO), depression stands out as a major contributor to disability, while suicide ranks fourth leading cause of death among individuals aged 15 to 29. [1] An electroencephalogram (EEG) is a commonly utilized tool to diagnose and assess the brain's electrical activity by applying electrodes to the scalp to detect and observe the electrical signals and activity patterns in the brain. Since EEG electrodes need to have good contact with the scalp to capture accurate brainwave data, achieving consistent and reliable contact with the scalp is difficult in a wearable form factor. Movements and shifts in the device, as well as hair interference, can affect the quality of EEG signals. EEG devices may be uncomfortable, inconvenient and expensive for regular use. [2] Mental health aside, cardiovascular disease (CVDs) stands as the primary global cause of mortality, claiming around 17.9 million lives annually according to WHO. [3] An electrocardiogram (ECG) can perform an examination that records the heart’s electrical pulses over a period. These signals are then transmitted to an ECG sensor, which produces a graphical representation of the heart’s electrical activity, often displayed as a graph or a series of waveforms. ECG can provide vital information about various aspects of cardiac health, including heart rate, the regularity of heartbeats, signs of abnormal rhythms, and the presence of certain heart conditions, such as arrhythmia ischemia or structural abnormalities. [4] One of the approaches to detect arrhythmia is to use ECG. [5] Arrhythmia refers to an irregular or abnormal heartbeat. [6] The heart typically beats in a regular, rhythmic pattern to pump blood throughout the body which can be shown in the ECG waveform in Figure 1. In instances of arrhythmia, the heart can exhibit deviations in its rhythm, which may denote excessive speed, rhythm or irregular pattern. [7] Arrhythmias may lead to symptoms such as palpitations, dizziness, breathlessness, or chest discomfort. [8] Thus, accurate diagnosis and monitoring of arrhythmias are essential to maintain good heart health.

Background Information

An ECG is utilized as a medical instrument for the heart’s electrical activity measurement and records over a period. A sample signal of the ECG wave is shown in Figure 1. The P-wave represents the electrical signal when the atria contract and push blood into the ventricles. [9] The inter-beat interval (IBI) is used for detecting heart rate, which can be computed based on the distance between R peaks in the ECG waveforms. [10] The QRS complex represents the electrical activity during the ventricles' contraction, which occurs as they pump blood out to circulate through the body. [9] Finally, the T-wave is the recovery phase. The standard placement of ECG is shown in Figure 2. According to Anatomy and Physiology 2, there are physiological interrelations between the heart and brain. [11] The autonomic innervation of the heart is a crucial part of the Autonomic Nervous System (ANS), which regulates involuntary bodily functions, including heart rate, blood pressure and respiratory rate. The regulation of heart rate is centred in the paired cardiovascular control centres within the medulla oblongata of the nervous system which are the sympathetic nervous system and the parasympathetic nervous system as shown in Figure 3. [11] While at rest, both centres offer subtle stimulation to the heart, contributing to the autonomic tone. The cardio accelerator triggers the release of the neurotransmitter norepinephrine, leading to a significant rise in heart rate, which takes place in both the sympathetic nervous system (SNS) and the sinoatrial (SA) node, while the cardioinhibitory release the neurotransmitter acetylcholine (Ach) into the parasympathetic nervous system (PNS). [11] The ANS would react based on the situation and alterations in the emotional experiences. For instance, a cardioaccelerator will be triggered in a “flight-or-fight” situation [12] whenever a person is in danger. Based on a national survey performed in the US, roughly 30% of American adults make use of healthcare wearable devices. [13] Among these users, about 47.33% use these devices daily, and a significant majority, representing 82.38%, express their willingness to share the health data collected from these wearables with their healthcare providers, emphasizing the potential for healthcare professionals to access vital information for better-informed medical decisions. [13] Thus, it reveals a compelling case for the development and commercialization of healthcare wearables which ultimately enhance the overall quality of healthcare services.

Aim

The objective of this project is to create a health monitoring system that integrates an ECG measurement kit with an STM32 edge computer and a cloud-based computer. This system comprises two key components: a model for predicting heart disease (cloud computer) and another for real-time emotion recognition (edge computer). The most important goal is to design an electronic circuit which is capable of precisely capturing bioelectric signals from the heart. Next, a data processing technique for obtaining characteristics that hold physiological and physical importance needs to be designed. [2] Additionally, the project explores the utilization of STM32 X-Linux-AI, facilitating the deployment of AI models into the embedded system. The model needs to be lightweight to be embedded into a device to implement edge computing. [2] [9]

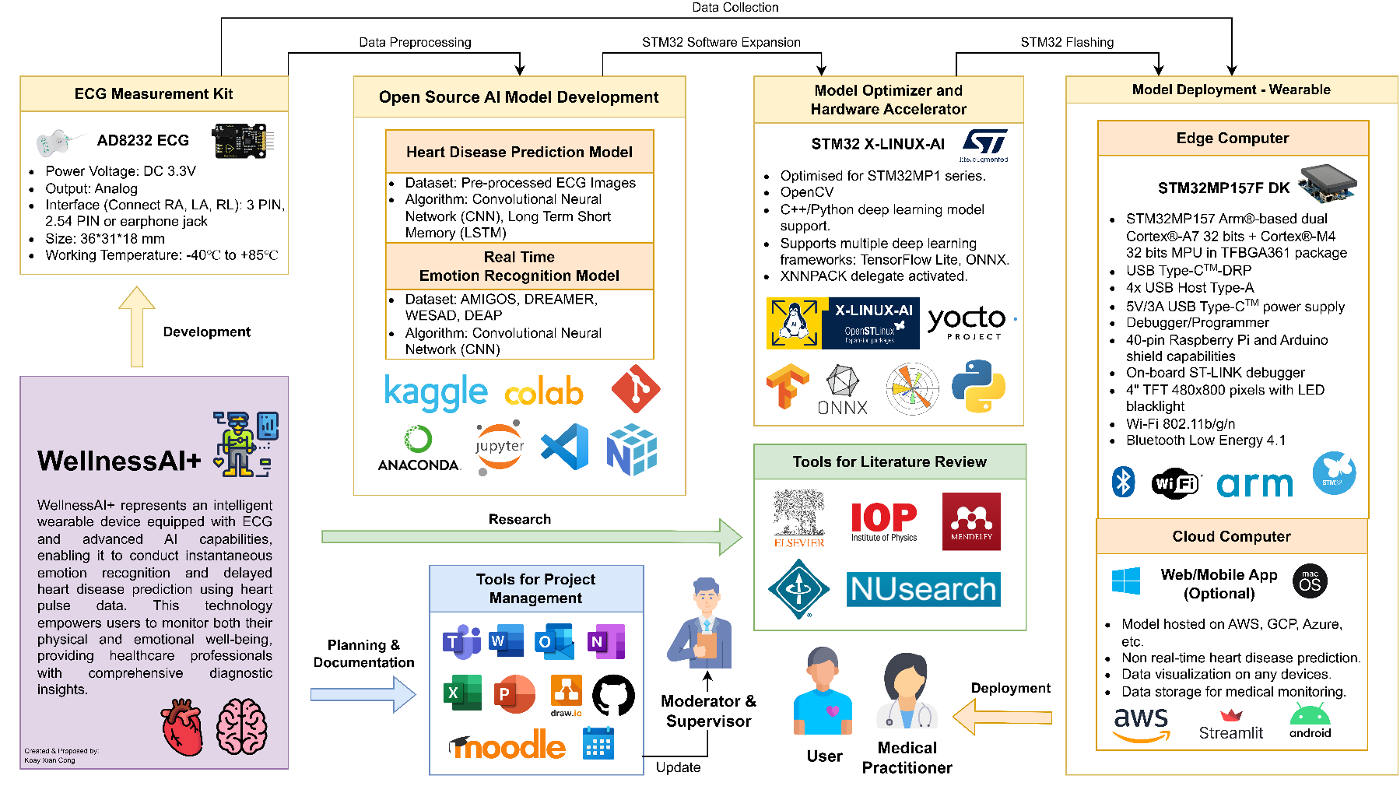
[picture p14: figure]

# 2. Specification

Requirements | Priority | Standards & Practices | Tests | Success Measure | Attainability & Achievability

Hardware
Integrating ECG measurement kit onto edge computer. | High | Ensure secure and accurate data transmission, and compliance with medical data protection standards. | Verify data connection between the ECG kit and edge computer. | Successful integration with consistent, accurate ECG data transmission. | Achievable with appropriate hardware interfaces and software development.
Create a real-life model of the wearable designed to integrate both software and hardware onto it. | Low (Stretch goal) | Utilize ergonomic design to ensure user comfort and safety. | Conduct usability tests with potential users. | Positive feedback from users on functionality and design. | Challenging but attainable as a stretch goal, may require additional resources and time.

Software
Coding program to connect ECG sensor with edge computer. | Medium | Adhere to coding and programming best practices, ensure modularity and standardization of code, and follow any relevant licenses for code libraries. Use open-source libraries. | Conduct tests and experiments to verify the accuracy and reliability of sensor data. | A program that effectively tests the ECG sensor and provides reliable data. | Achievable with the necessary programming skills and resources.
Coding program to create, test and heart disease prediction model. | High | | Conduct tests to verify the accuracy and effectiveness of the heart disease prediction. | A functional program that successfully creates and tests the heart disease prediction model.
Coding program to create, test and deploy emotion recognition model. | High | | Conduct tests to verify the accuracy and effectiveness of the emotion recognition. | A functional program that successfully creates and tests the emotion recognition model.
Coding program to display data collected from sensor and model output. | Low (Stretch goal) | | Validate the program’s ability to display sensor data and model output results effectively. | Development of a program that successfully displays sensor data and model output results. | Achievable as a stretch goal, may require additional software development resources.

# 3. Methodology

## 3.1 Setting up software and hardware for STM32MP157F-DK2.

STM32MP157F-DK2 [14] is power-efficient and suitable for real-time tasks which are designed for low power consumption, making it well-suited for wearable devices. The presence of an ARM Cortex-M4 microcontroller on the edge computer allows for real-time control, which can be crucial for the deployment of real-time emotion recognition. It comes with 4” TFT 480x800 pixels, allowing data and model output to be displayed. However, compared to Raspberry Pi, it has fewer readily available resources and support due to smaller communities. STM32 Cube programmer [14] is part of the STM32Cube ecosystem, which provides a comprehensive set of development tools for STM32 microcontrollers and microprocessors. However, STM32 Cube Programmer can be resource-intensive, particularly when working with large projects. The potential additional task includes familiarizing with Ubuntu OS and STM32 Cube programmer.

## 3.2 Integrating ECG kit onto edge computer.

AD8232 ECG measurement kit [15] is chosen for its precision in collecting vital heart activity. However, wearable ECG sensors may not be as comfortable for long-term use, potentially affecting user adoption and compliance. The potential additional tasks include performing tests and experiments to verify that the ECG kit is functioning correctly and can collect ECG data accurately and implementation of data transmission protocols to ensure that ECG data collected by the kit can be transmitted to the edge computer in real time.

## 3.3 Open-Source AI Model Development.

Python is a widely used programming language for ML and DL. It has various libraries available for data manipulation, analysis, visualization, etc in AI model development. However, advanced DL models may require substantial computational resources, which could impact performance on resource-constraints systems. Anaconda provides a convenient environment for managing Python packages and creating isolated development environments. Since there are 2 models developed: heart disease prediction and emotion recognition, this feature ensures package compatibility between projects. Deep learning libraries (TensorFlow Lite etc.) enable AI model development more accessible and efficient with optimization tools and GPU acceleration available. Git/GitHub is a version control system that allows for efficient version tracking in AI model development. The potential additional tasks include familiarization with software tools and DL models, and performing data preprocessing, which may involve tasks like data augmentation, normalization and retraining models available online to validate the model's accuracy and performance.

## 3.4 Model Optimizer and Hardware Accelerator.

STM32 X-LINUX-AI is an expansion package that targets artificial intelligence for STM32MP1 series microprocessors. There are limited model architectures available.

## 3.5 Deployment of AI models into edge computers and cloud computers.

Cloud platforms like AWS offer access to powerful GPU instances, which significantly accelerate AI model inference and training. It also offers APIs to link the results to front-end web/mobile apps. However, AI models deployed in the cloud may experience network latency, which can be a concern for real-time applications. The potential additional task includes ensuring that the AI models are optimized for deployment on both the edge and cloud platforms.

# 4. Risk Management and Mitigations

**Importance = Severity + Likelihood [Low = 1, Medium = 2, High = 3]. The higher the value, the more important the risk.

Events | Timeline (Week) | Risks | Mitigation | Impact | Pre, Post Mitigation Severity & Likelihood | **
Integrating ECG kit onto edge computer. | 10 – 14 | Incompatibility issue between edge computer and ECG measurement kit. | Perform compatibility testing and refer to hardware documentation. | Delay in project timeline. | Pre: Low Post: Low Likelihood: Low | 3
| | Short circuit due to incorrect power connections. | Adhering to the documentation and requirements. | Delay in project timeline if new microcontroller order is needed. | Pre: Medium Post: Low Likelihood: Low | 4
Open-Source AI Model Development | 14 – 28 | Advanced deep learning models may require substantial computational resources, impacting performance on resource-constrained systems. | Optimize and simplify AI models, employ cloud-based resources when necessary, and manage hardware efficiently. | Delayed model training. Performance degradation. | Pre: Medium Post: Medium Likelihood: High | 7
| | An exclusive reliance on deep learning methods proved insufficient in identifying all crucial ECG signal features. [9] [7] | A hybrid strategy is applied to improve detection efficiency. [9] | Inaccurate results. Misdiagnoses. | Pre: High Post: Medium Likelihood: High | 8
| | ECG signal analysis demands a substantial volume of data for accurate results. [7] | Performing data augmentation to increase the size of the dataset available. | Inaccurate results. Misdiagnoses. | Pre: High Post: Medium Likelihood: High | 8
Deployment of AI models into edge computer and cloud computer | 27 – 31 | The model takes too long to produce output. | Rigorously test AI model deployment on the edge computer to ensure real-time performance and functionality. | Model inaccuracies and reduced usability. | Pre: High Post: High Likelihood: High | 9
| | API and model compatibility issues. | Perform test cases with available AI models before training a new model. | Delay in project timeline. | Pre: High Post: Medium Likelihood: High | 8
| | Network latency when deployed in the cloud. | Optimize model size. | Delayed response time. | Pre: High Post: Medium Likelihood: High | 8

# 5. Time Plan

The Gantt Chart for time planning has been structured considering the interdependencies between tasks. Within the "Design solutions/applications" phase, there's a requirement to set up and test ECG sensors, STM32MP157F, and software. This precedes the design of the model architecture before moving on to the development of the AI model. The deployment of the model and sensor hinges on the completion of the AI model, so it follows this phase. To ensure tasks stay on track, there are project milestones marked at various points, and four progress reviews are scheduled:

Moderator Review 1 is planned between Week 9 – Week 10 to discuss project objectives and project specifications. Moderator Review 2 planned between Week 13 – Week 14 is to discuss the process made upon a program that tests functions of edge computers and experiments made to ensure accurate measurements of sensors. Moderator Review 3 planned for Week 25 is to discuss the development and progress of the emotion recognition model, heart disease prediction model and program that connects sensors with AI model. Moderator Review 4, which is planned between Week 35 – Week 36 is to discuss the deployment of the heart disease prediction model developed onto a cloud computer and, the deployment of the emotion recognition model developed onto the edge computer. In light of the potential risks and issues mentioned earlier, a parallelization technique is applied to enable the execution of multiple tasks simultaneously, particularly those that are independent of one another. Additionally, provisions have been made for debugging codes and addressing bugs that may surface during model development and user testing. Improvements can be made based on feedback obtained from users. The Gantt chart also incorporates error bars to account for uncertainties. In cases where previously unidentified risks arise, these error bars provide additional time to mitigate the issues. Lastly, the Gantt chart includes optional and supplementary tasks, described as stretch goals, which can be pursued if there is available time before each progress review.

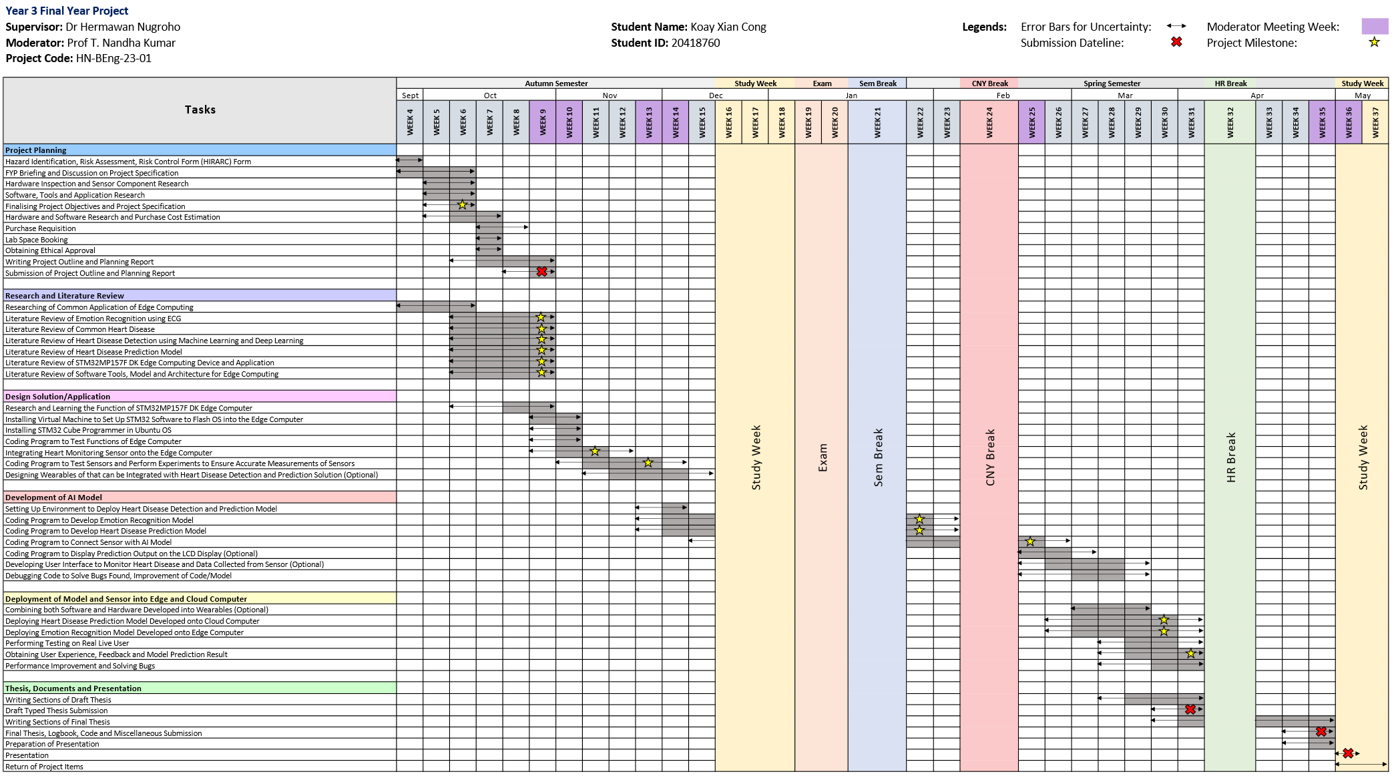
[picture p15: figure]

Gantt Chart

# 6. References

[1] “Mental health.” Accessed: Oct. 19, 2023. [Online]. Available: https://www.who.int/health-topics/mental-health#tab=tab_1

[2] X. Wang, J. Zhang, C. He, H. Wu, and L. Cheng, “A Novel Emotion Recognition Method Based on the Feature Fusion of Single-Lead EEG and ECG Signals,” IEEE Internet Things J, 2023, doi: 10.1109/JIOT.2023.3320269.

[3] “Cardiovascular diseases.” Accessed: Oct. 19, 2023. [Online]. Available: https://www.who.int/health-topics/cardiovascular-diseases#tab=tab_1

[4] Ed Burns and Mike Cadogan, “Myocardial Ischaemia • LITFL • ECG Library Diagnosis.” Accessed: Oct. 19, 2023. [Online]. Available: https://litfl.com/myocardial-ischaemia-ecg-library/

[5] H. Yang and Z. Wei, “Arrhythmia Recognition and Classification Using Combined Parametric and Visual Pattern Features of ECG Morphology,” IEEE Access, vol. 8, 2020, doi: 10.1109/ACCESS.2020.2979256.

[6] K. Subramanian and N. K. Prakash, “Machine learning based cardiac arrhythmia detection from ECG signal,” in Proceedings of the 3rd International Conference on Smart Systems and Inventive Technology, ICSSIT 2020, 2020. doi: 10.1109/ICSSIT48917.2020.9214077.

[7] T. Padma, A. Uday Kiran, C. Jahnavi, S. Rahul, N. Raja, and M. Kamal Kumar, “Detection and Classification of Arrhythmias by Deploying Deep Learning Models,” in Journal of Physics: Conference Series, 2022. doi: 10.1088/1742-6596/2325/1/012053.

[8] A. A. Salman and A. Ibarahim, “Detection of Cardiac Arrhythmias in Electroc Ardiograms Using Deep Learning,” in ISMSIT 2022 - 6th International Symposium on Multidisciplinary Studies and Innovative Technologies, Proceedings, 2022. doi: 10.1109/ISMSIT56059.2022.9932742.

[9] A. L. Golande and T. Pavankumar, “Optical electrocardiogram based heart disease prediction using hybrid deep learning,” J Big Data, vol. 10, no. 1, pp. 139–13, 2023, doi: 10.1186/s40537-023-00820-6.

[10] A. Tjolleng et al., “Classification of a Driver’s cognitive workload levels using artificial neural network on ECG signals,” Appl Ergon, vol. 59, no. Pt A, pp. 326–332, 2017, doi: 10.1016/j.apergo.2016.09.013.

[11] J. G. Betts et al., Anatomy & Physiology -OpenStax. 2013.

[12] P. J. Bota, C. Wang, A. L. N. Fred, and H. Placido Da Silva, “A Review, Current Challenges, and Future Possibilities on Emotion Recognition Using Machine Learning and Physiological Signals,” IEEE access, vol. 7, pp. 140990–141020, 2019, doi: 10.1109/ACCESS.2019.2944001.

[13] R. Chandrasekaran, V. Katthula, and E. Moustakas, “Patterns of Use and Key Predictors for the Use of Wearable Health Care Devices by US Adults: Insights from a National Survey,” Journal of Medical Internet Research, vol. 22, no. 10. 2020. doi: 10.2196/22443.

[14] “Unpack the STM32MP157x-DK2 board - stm32mpu.” Accessed: Oct. 22, 2023. [Online]. Available: https://wiki.st.com/stm32mpu/wiki/Getting_started/STM32MP1_boards/STM32MP157x-DK2/Let%27s_start/Unpack_the_STM32MP157x-DK2_board

[15] “Ks0261 keyestudio AD8232 ECG Measurement Heart Monitor Sensor Module - Keyestudio Wiki.” Accessed: Oct. 22, 2023. [Online]. Available: https://wiki.keyestudio.com/Ks0261_keyestudio_AD8232_ECG_Measurement_Heart_Monitor_Sensor_Module#Test_Result

[16] J. Gordon Betts et al., Anatomy and Physiology 2e. Houston, Texas: OpenStax, 2022.

[17] X. Wang, J. Zhang, C. He, H. Wu, and L. Cheng, “A Novel Emotion Recognition Method Based on the Feature Fusion of Single-Lead EEG and ECG Signals,” IEEE Internet Things J, 2023, doi: 10.1109/JIOT.2023.3320269.

[18] M. Roesler, L. Mohimont, F. Alin, N. Gaveau, and L. A. Steffenel, “Deploying Deep Neural Networks on Edge Devices for Grape Segmentation,” in Communications in Computer and Information Science, 2021. doi: 10.1007/978-3-030-88259-4_3.

# 7. Appendix

Figure 1 from Fig : A cardiac cycle of an ECG Classification of Arrhythmia | Semantic Scholar

Figure 1. EEG cycle.


Figure 2. Standard placement of ECG. [16]


Figure 3. Autonomic Innervation of the Heart.

Project Specifications

Project Title | | Emotion recognition and heart disease detection based on ECG analysis using STM32 MPU.
Project Code | | HN-BEng-23-01
Supervisor | | Hermawan Nugroho
Moderator | | Prof T. Nandha Kumar

Project Description

The perception, cognition, and decision-making processes which people engage daily are significantly influenced by their emotions, which is important for human contact and communication. People's numerous physiological signs behave differently depending on how they are feeling. EEG (electroencephalogram) is a typical biological signal utilized for emotion recognition. However, several studies have shown that accurate emotion recognition using multichannel ECG (electrocardiogram) information is possible [1].

STM32 is a family of microcontrollers created by STMicroelectronics. X-LINUX-AI is an STM32 MPU OpenSTLinux Expansion Package that targets artificial intelligence for STM32MPx series devices. It contains Linux AI frameworks, development tools, as well as applications such as computer vision [2].

In the project, the aim is to explore and develop an edge intelligence system which can run emotion recognition and heart disease detection using ECG data.

References:

[1] X. Wang, J. Zhang, C. He, H. Wu, and L. Cheng, “A Novel Emotion Recognition Method Based on the Feature Fusion of Single-Lead EEG and ECG Signals,” IEEE Internet Things J, 2023, doi: 10.1109/JIOT.2023.3320269.

[2] M. Roesler, L. Mohimont, F. Alin, N. Gaveau, and L. A. Steffenel, “Deploying Deep Neural Networks on Edge Devices for Grape Segmentation,” in Communications in Computer and Information Science, 2021. doi: 10.1007/978-3-030-88259-4_3.
Project Objectives | | 1. Explore and improve algorithms for emotion recognition using ECG data. 2. Explore and improve algorithms for heart disease detection using ECG data. 3. Integrate the emotion recognition module (real time analysis) and heart disease detection (offline analysis). 4. Adopt the developed algorithms on STM32 MPU
Project Deliverables | | 1. Emotion recognition algorithm using ECG data. 2. Heart disease detection using ECG data. 3. STM32 MPU based edge intelligence system.
Ratio of HW/SW/Research | | HW SW Research/Investigation/Design 20 40 40
Lab Space Requirements | | ☒ Fixed Space ☐ Ad-hoc Space ☐ Others. Space in the drone-lab
Software (This is software usually supported in the Software Lab) | | X-Linux-AI, STM32MX, STM32IDE

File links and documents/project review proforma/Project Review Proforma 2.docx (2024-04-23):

Summarised Planned State of Project:

Design Solution/Application:

1. Designing wearables that can be integrated with emotion classification and heart disease prediction models. (Optional)

Development of AI Model:

1. Setting up an environment to deploy a heart disease detection and prediction model.
2. Coding program to develop emotion recognition model.
3. Coding program to develop heart disease prediction model.
4. Coding program to connect sensor with AI model.

Deployment of Model and Sensor into Edge and Cloud Computer:

1. Deploying emotion recognition model developed onto edge computer.

Actual Progress Since Last Review

Design Solution/Application:

1. The wearables design was done according to plan.

Development of AI Model:

1. Environment and libraries for edge computer and AI model have been set up.
2. The dataset was downloaded, and a customized dataset was created.
3. TensorFlow model was trained.
4. TensorFlow Lite model was created and uploaded onto STM32Cube IDE.
5. Debug and solve flash memory insufficient issues.
6. A program that connects sensors with an AI model has been created.
7. The task was performed according to plan.

Deployment of Model and Sensor into Edge and Cloud Computer:

1. Debugging deployment of AI models and sensor code.
2. The task is still ongoing.

Next Steps

1. Start writing the thesis draft.
2. Complete the first cycle of obtaining real-time inference using values from sensors.
3. Debugging firmware deployment on STM32CubeIDE.

Supervisor Feedback

The supervisor recommended commencing the drafting of the thesis and focusing on completing the initial phase of acquiring real-time emotion classification inference utilizing sensor data.

Project Review Proforma – Review number: 2 Date: 5/2/2024

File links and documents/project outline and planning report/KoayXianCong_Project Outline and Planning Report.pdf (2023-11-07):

## The University of Nottingham

### Faculty of Engineering

### Department of Electrical and Electronic Engineering

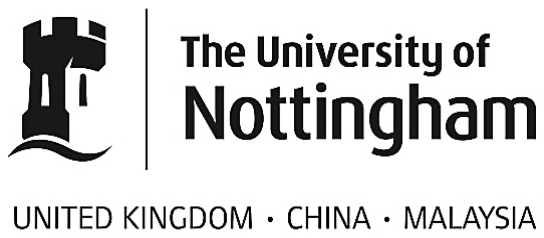
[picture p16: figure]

EEEE3026
Project Outline and Planning Report

WellnessAI+: Elevating Mental, Emotional and Physical Health with ECG-Enhanced Artificial intelligence

AUTHOR | : | KOAY XIAN CONG
ID | : | 20418760
SUPERVISOR | : | DR HERMAWAN NUGROHO
MODERATOR | : | PROF T. NANDHA KUMAR
DATE | : | 30th OCT 2023

## Contents

## 1. Overview of the Project

Introduction
The focus of this project is to incorporate electrocardiogram (ECG) and artificial intelligence (AI) driven algorithms to offer a groundbreaking approach to edge computing to not only predict heart disease but also delve into the depths of human emotions. This dual-purpose capability signifies a pivotal leap forward in personalized healthcare and wellness management, ushering in a new era of preventative and predictive medicine. The deployment of AI into edge computers powered by ARM Cortex-M chips will also be further explored and discussed.

Problem Statement
According to the World Health Organization (WHO), depression stands out as a major contributor to disability, while suicide ranks fourth leading cause of death among individuals aged 15 to 29.
[1] An electroencephalogram (EEG) is a commonly utilized tool to diagnose and assess the brain's electrical activity by applying electrodes to the scalp to detect and observe the electrical signals and activity patterns in the brain. Since EEG electrodes need to have good contact with the scalp to capture accurate brainwave data, achieving consistent and reliable contact with the scalp is difficult in a wearable form factor. Movements and shifts in the device, as well as hair interference, can affect the quality of EEG signals. EEG devices may be uncomfortable, inconvenient and expensive for regular use. [2] Mental health aside, cardiovascular disease (CVDs) stands as the primary global cause of mortality, claiming around 17.9 million lives annually according to WHO.
[3] An electrocardiogram (ECG) can perform an examination that records the heart’s electrical pulses over a period. These signals are then transmitted to an ECG sensor, which produces a graphical representation of the heart’s electrical activity, often displayed as a graph or a series of waveforms. ECG can provide vital information about various aspects of cardiac health, including heart rate, the regularity of heartbeats, signs of abnormal rhythms, and the presence of certain heart conditions, such as arrhythmia ischemia or structural abnormalities. [4] One of the approaches to detect arrhythmia is to use ECG. [5] Arrhythmia refers to an irregular or abnormal heartbeat. [6] The heart typically beats in a regular, rhythmic pattern to pump blood throughout the body which can be shown in the ECG waveform in Figure 1. In instances of arrhythmia, the heart can exhibit deviations in its rhythm, which may denote excessive speed, rhythm or irregular pattern. [7] Arrhythmias may lead to symptoms such as palpitations, dizziness, breathlessness, or chest discomfort. [8] Thus, accurate diagnosis and monitoring of arrhythmias are essential to maintain good heart health.

Background Information
An ECG is utilized as a medical instrument for the heart’s electrical activity measurement and records over a period. A sample signal of the ECG wave is shown in Figure 1. The P-wave represents the electrical signal when the atria contract and push blood into the ventricles. [9] The inter-beat interval (IBI) is used for detecting heart rate, which can be computed based on the distance between R peaks in the ECG waveforms. [10] The QRS complex represents the electrical activity during the ventricles' contraction, which occurs as they pump blood out to circulate through the body. [9] Finally, the T-wave is the recovery phase. The standard placement of ECG is shown in Figure 2. According to Anatomy and Physiology 2, there are physiological interrelations between the heart and brain. [11] The autonomic innervation of the heart is a crucial part of the Autonomic Nervous System (ANS), which regulates involuntary bodily functions, including heart rate, blood pressure and respiratory rate. The regulation of heart rate is centred in the paired cardiovascular control centres within the medulla oblongata of the nervous system which are the sympathetic nervous system and the parasympathetic nervous system as shown in Figure 3. [11] While at rest, both centres offer subtle stimulation to the heart, contributing to the autonomic tone. The cardio accelerator triggers the release of the neurotransmitter norepinephrine, leading to a significant rise in heart rate, which takes place in both the sympathetic nervous system (SNS) and the sinoatrial (SA) node, while the cardioinhibitory release the neurotransmitter acetylcholine (Ach) into the parasympathetic nervous system (PNS). [11] The ANS would react based on the situation and alterations in the emotional experiences. For instance, a cardioaccelerator will be triggered in a “flight-or-fight” situation [12] whenever a person is in danger. Based on a national survey performed in the US, roughly 30% of American adults make use of healthcare wearable devices. [13] Among these users, about 47.33% use these devices daily, and a significant majority, representing 82.38%, express their willingness to share the health data collected from these wearables with their healthcare providers, emphasizing the potential for healthcare professionals to access vital information for better-informed medical decisions. [13] Thus, it reveals a compelling case for the development and commercialization of healthcare wearables which ultimately enhance the overall quality of healthcare services.

Aim
The objective of this project is to create a health monitoring system that integrates an ECG measurement kit with an STM32 edge computer and a cloud-based computer. This system comprises two key components: a model for predicting heart disease (cloud computer) and another for real-time emotion recognition (edge computer). The most important goal is to design an electronic circuit which is capable of precisely capturing bioelectric signals from the heart. Next, a data processing technique for obtaining characteristics that hold physiological and physical importance needs to be designed. [2] Additionally, the project explores the utilization of STM32 X-Linux-AI, facilitating the deployment of AI models into the embedded system. The model needs to be lightweight to be embedded into a device to implement edge computing. [2] [9]

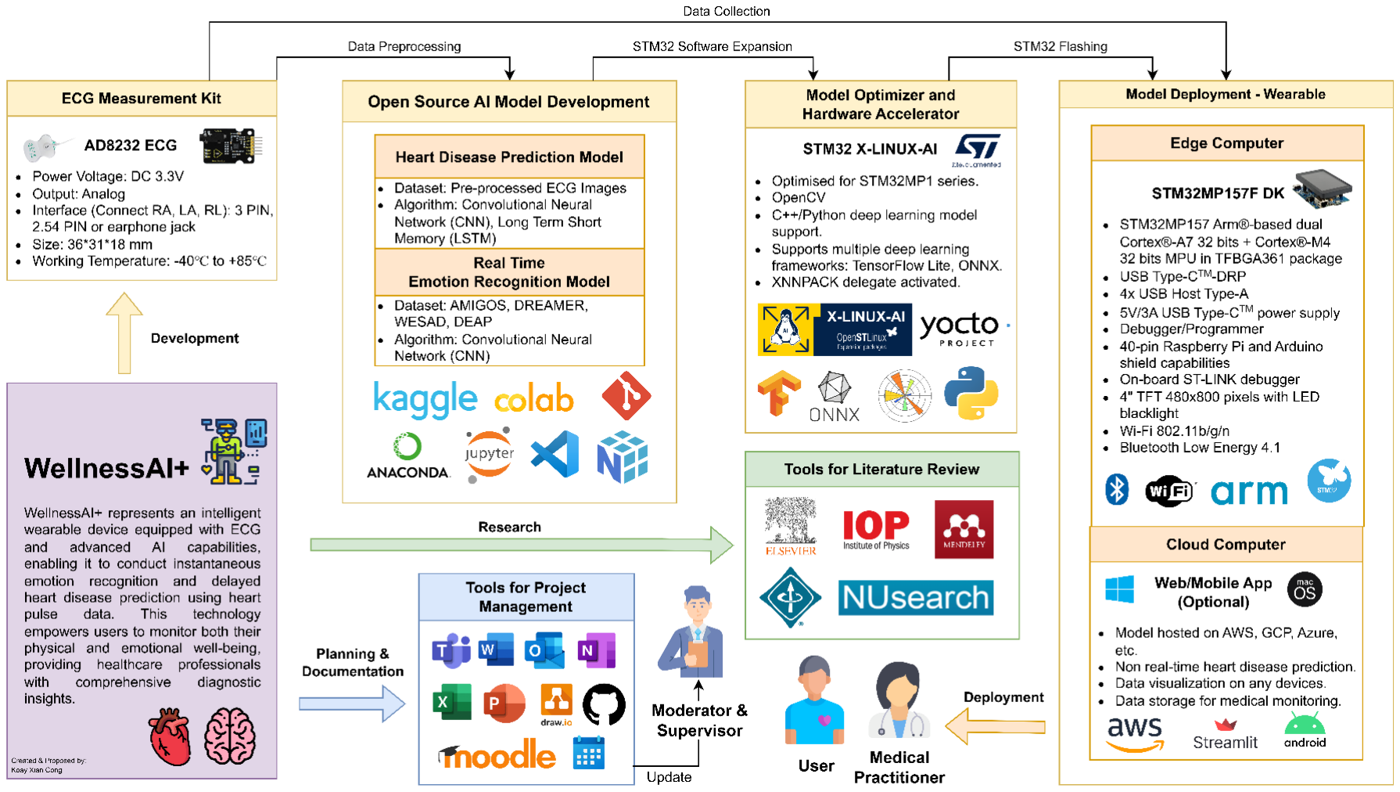
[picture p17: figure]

## 2. Specification

Requirements | Priority | Standards &
Practices | Tests | Success Measure | Attainability & Achievability
| Hardware
Integrating ECG measurement kit onto edge computer. | High | Ensure secure and accurate data transmission, and compliance with medical data protection standards. | Verify data connection between the ECG kit and edge computer. | Successful integration with consistent, accurate ECG data transmission. | Achievable with appropriate hardware interfaces and software development.
Create a real-life model of the wearable designed to integrate both software and hardware onto it. | Low (Stretch goal) | Utilize ergonomic design to ensure user comfort and safety. | Conduct usability tests with potential users. | Positive feedback from users on functionality and design. | Challenging but attainable as a stretch goal, may require additional resources and time.

Software
Coding program to connect ECG sensor with edge computer. | | Conduct tests and experiments to verify the accuracy and reliability of sensor data. | A program that effectively tests the ECG sensor and provides reliable data. | Achievable with the necessary programming skills and resources.
Coding program to create, test and heart disease prediction model. | High | Conduct tests to verify the accuracy and effectiveness of the heart disease prediction. | A functional program that successfully creates and tests the heart disease prediction model.
Coding program to create, test and deploy emotion recognition model. | High | Conduct tests to verify the accuracy and effectiveness of the emotion recognition. | A functional program that successfully creates and tests the emotion recognition model.
Coding program to display data collected from sensor and model output. | Low (Stretch goal) | Validate the program’s ability to display sensor data and model output results effectively. | Development of a program that successfully displays sensor data and model output results. | Achievable as a stretch goal, may require additional software development resources.
Medium | Adhere to coding and
programming | best
practices, | ensure
modularity | and
standardization | of
code, and follow any
relevant licenses for
code libraries. Use
open-source
libraries.

## 3. Methodology

3.1 Setting up software and hardware for STM32MP157F-DK2.
STM32MP157F-DK2 [14] is power-efficient and suitable for real-time tasks which are designed for low power consumption, making it well-suited for wearable devices. The presence of an ARM Cortex-M4 microcontroller on the edge computer allows for real-time control, which can be crucial for the deployment of real-time emotion recognition. It comes with 4” TFT 480x800 pixels, allowing data and model output to be displayed. However, compared to Raspberry Pi, it has fewer readily available resources and support due to smaller communities. STM32 Cube programmer
[14] is part of the STM32Cube ecosystem, which provides a comprehensive set of development tools for STM32 microcontrollers and microprocessors. However, STM32 Cube Programmer can be resource-intensive, particularly when working with large projects. The potential additional task includes familiarizing with Ubuntu OS and STM32 Cube programmer.

3.2 Integrating ECG kit onto edge computer.
AD8232 ECG measurement kit [15] is chosen for its precision in collecting vital heart activity. However, wearable ECG sensors may not be as comfortable for long-term use, potentially affecting user adoption and compliance. The potential additional tasks include performing tests and experiments to verify that the ECG kit is functioning correctly and can collect ECG data accurately and implementation of data transmission protocols to ensure that ECG data collected by the kit can be transmitted to the edge computer in real time.

3.3 Open-Source AI Model Development.
Python is a widely used programming language for ML and DL. It has various libraries available for data manipulation, analysis, visualization, etc in AI model development. However, advanced DL models may require substantial computational resources, which could impact performance on resource-constraints systems. Anaconda provides a convenient environment for managing Python packages and creating isolated development environments. Since there are 2 models developed: heart disease prediction and emotion recognition, this feature ensures package compatibility between projects. Deep learning libraries (TensorFlow Lite etc.) enable AI model development more accessible and efficient with optimization tools and GPU acceleration available. Git/GitHub is a version control system that allows for efficient version tracking in AI model development. The potential additional tasks include familiarization with software tools and DL models, and performing data preprocessing, which may involve tasks like data augmentation, normalization and retraining models available online to validate the model's accuracy and performance.

3.4 Model Optimizer and Hardware Accelerator.
STM32 X-LINUX-AI is an expansion package that targets artificial intelligence for STM32MP1 series microprocessors. There are limited model architectures available.

3.5Deployment of AI models into edge computers and cloud computers.
Cloud platforms like AWS offer access to powerful GPU instances, which significantly accelerate AI model inference and training. It also offers APIs to link the results to front-end web/mobile apps. However, AI models deployed in the cloud may experience network latency, which can be a concern for real-time applications. The potential additional task includes ensuring that the AI models are optimized for deployment on both the edge and cloud platforms.

## 4. Risk Management and Mitigations

**Importance = Severity + Likelihood [Low = 1, Medium = 2, High = 3]. The higher the value, the more important the risk.

Events | Timeline (Week) | Risks | Mitigation | Impact | Pre, Post Mitigation Severity & Likelihood | **
Integrating ECG kit onto edge computer. | 10 – 14 | Incompatibility issue between edge computer and ECG measurement kit. | Perform compatibility testing and refer to hardware documentation. | Delay in project timeline. | Pre: Low Post: Low Likelihood: Low | 3
| | Short circuit due to incorrect power connections. | Adhering to the documentation and requirements. | Delay in project timeline if new microcontroller order is needed. | Pre: Medium Post: Low Likelihood: Low | 4
Open-Source AI Model Development | 14 – 28 | Advanced deep learning models may require substantial computational resources, impacting performance on resource-constrained systems. | Optimize and simplify AI models, employ cloud-based resources when necessary, and manage hardware efficiently. | Delayed model training. Performance degradation. | Pre: Medium Post: Medium Likelihood: High | 7
| | An exclusive reliance on deep learning methods proved insufficient in identifying all crucial ECG signal features. [9] [7] | A hybrid strategy is applied to improve detection efficiency. [9] | Inaccurate results. Misdiagnoses. | Pre: High Post: Medium Likelihood: High | 8
| | ECG signal analysis demands a substantial volume of data for accurate results. [7] | Performing data augmentation to increase the size of the dataset available. | Inaccurate results. Misdiagnoses. | Pre: High Post: Medium Likelihood: High | 8
Deployment of AI models into edge computer and cloud computer | 27 – 31 | The model takes too long to produce output. | Rigorously test AI model deployment on the edge computer to ensure real-time performance and functionality. | Model inaccuracies and reduced usability. | Pre: High Post: High Likelihood: High | 9
| | API and model compatibility issues. | Perform test cases with available AI models before training a new model. | Delay in project timeline. | Pre: High Post: Medium Likelihood: High | 8
| | Network latency when deployed in the cloud. | Optimize model size. | Delayed response time. | Pre: High Post: Medium Likelihood: High | 8

## 5. Time Plan

The Gantt Chart for time planning has been structured considering the interdependencies between tasks. Within the "Design solutions/applications" phase, there's a requirement to set up and test ECG sensors, STM32MP157F, and software. This precedes the design of the model architecture before moving on to the development of the AI model. The deployment of the model and sensor hinges on the completion of the AI model, so it follows this phase. To ensure tasks stay on track, there are project milestones marked at various points, and four progress reviews are scheduled: Moderator Review 1 is planned between Week 9 – Week 10 to discuss project objectives and project specifications. Moderator Review 2 planned between Week 13 – Week 14 is to discuss the process made upon a program that tests functions of edge computers and experiments made to ensure accurate measurements of sensors. Moderator Review 3 planned for Week 25 is to discuss the development and progress of the emotion recognition model, heart disease prediction model and program that connects sensors with AI model. Moderator Review 4, which is planned between Week 35 – Week 36 is to discuss the deployment of the heart disease prediction model developed onto a cloud computer and, the deployment of the emotion recognition model developed onto the edge computer. In light of the potential risks and issues mentioned earlier, a parallelization technique is applied to enable the execution of multiple tasks simultaneously, particularly those that are independent of one another. Additionally, provisions have been made for debugging codes and addressing bugs that may surface during model development and user testing. Improvements can be made based on feedback obtained from users. The Gantt chart also incorporates error bars to account for uncertainties. In cases where previously unidentified risks arise, these error bars provide additional time to mitigate the issues. Lastly, the Gantt chart includes optional and supplementary tasks, described as stretch goals, which can be pursued if there is available time

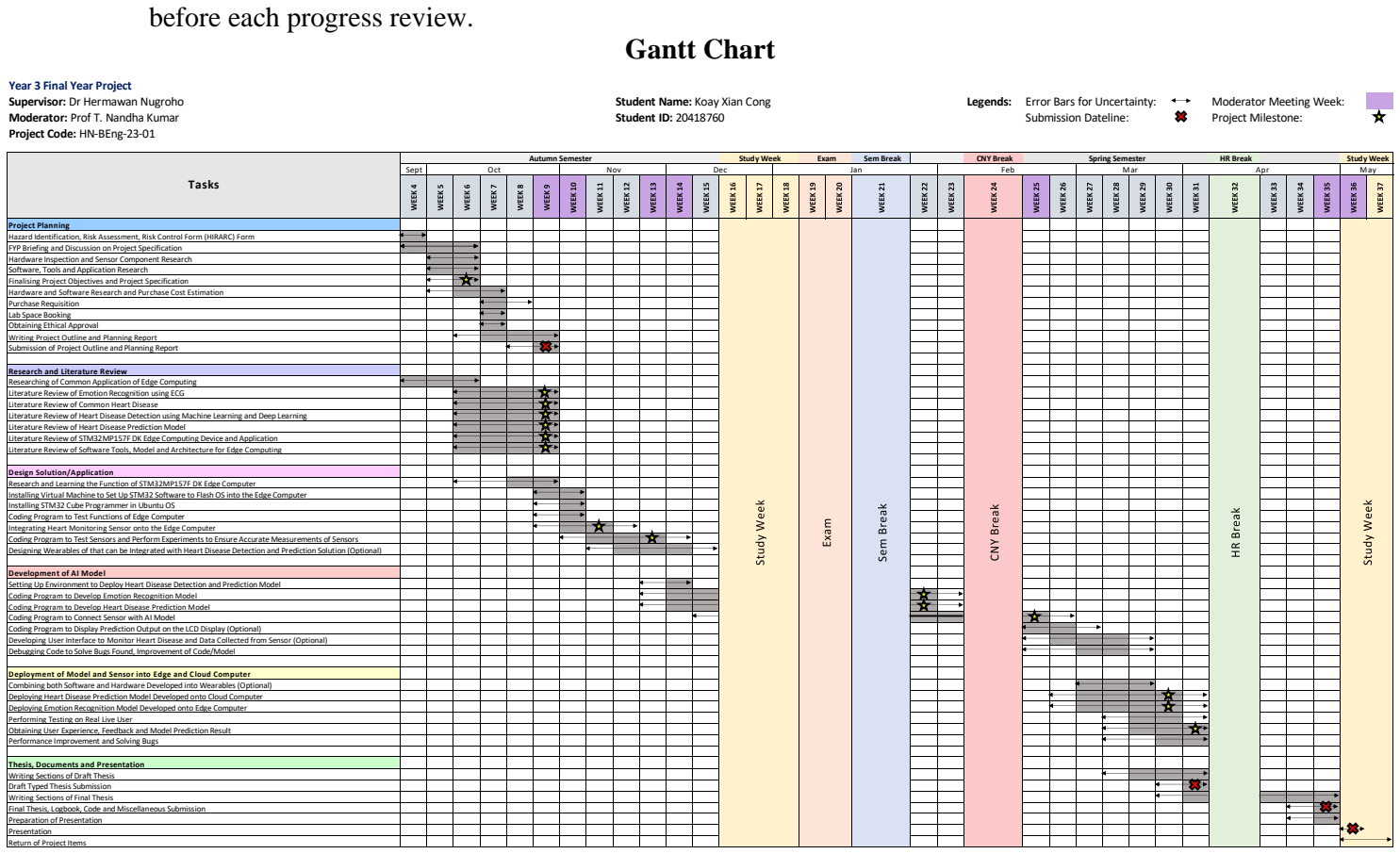
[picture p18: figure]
before each progress review.; Gantt Chart

## 6. References

[1] “Mental health.” Accessed: Oct. 19, 2023. [Online]. Available: https://www.who.int/health-topics/mental-health#tab=tab_1
[2] X. Wang, J. Zhang, C. He, H. Wu, and L. Cheng, “A Novel Emotion Recognition Method Based on the Feature Fusion of Single-Lead EEG and ECG Signals,” IEEE Internet Things J, 2023, doi: 10.1109/JIOT.2023.3320269.
[3] | “Cardiovascular | diseases.” | Accessed: | Oct. | 19, | 2023. | [Online]. | Available:
https://www.who.int/health-topics/cardiovascular-diseases#tab=tab_1
[4] Ed Burns and Mike Cadogan, “Myocardial Ischaemia • LITFL • ECG Library Diagnosis.” Accessed: Oct. 19, 2023. [Online]. Available: https://litfl.com/myocardial-ischaemia-ecg-
| library/
[5] H. Yang and Z. Wei, “Arrhythmia Recognition and Classification Using Combined Parametric and Visual Pattern Features of ECG Morphology,” IEEE Access, vol. 8, 2020, doi: 10.1109/ACCESS.2020.2979256.
[6] K. Subramanian and N. K. Prakash, “Machine learning based cardiac arrhythmia detection from ECG signal,” in Proceedings of the 3rd International Conference on Smart Systems and Inventive Technology, ICSSIT 2020, 2020. doi: 10.1109/ICSSIT48917.2020.9214077.
[7] T. Padma, A. Uday Kiran, C. Jahnavi, S. Rahul, N. Raja, and M. Kamal Kumar, “Detection and Classification of Arrhythmias by Deploying Deep Learning Models,” in Journal of Physics: Conference Series, 2022. doi: 10.1088/1742-6596/2325/1/012053.
[8] A. A. Salman and A. Ibarahim, “Detection of Cardiac Arrhythmias in Electroc Ardiograms Using Deep Learning,” in ISMSIT 2022 - 6th International Symposium on Multidisciplinary
Studies | and | Innovative | Technologies, | Proceedings, | 2022. | doi:
10.1109/ISMSIT56059.2022.9932742.
[9] A. L. Golande and T. Pavankumar, “Optical electrocardiogram based heart disease prediction using hybrid deep learning,” J Big Data, vol. 10, no. 1, pp. 139–13, 2023, doi: 10.1186/s40537-023-00820-6.
[10] A. Tjolleng et al., “Classification of a Driver’s cognitive workload levels using artificial neural network on ECG signals,” Appl Ergon, vol. 59, no. Pt A, pp. 326–332, 2017, doi: 10.1016/j.apergo.2016.09.013.
[11] J. G. Betts et al., Anatomy & Physiology -OpenStax. 2013.
[12] P. J. Bota, C. Wang, A. L. N. Fred, and H. Placido Da Silva, “A Review, Current Challenges, and Future Possibilities on Emotion Recognition Using Machine Learning and Physiological Signals,” IEEE access, vol. 7, pp. 140990–141020, 2019, doi: 10.1109/ACCESS.2019.2944001.
[13] R. Chandrasekaran, V. Katthula, and E. Moustakas, “Patterns of Use and Key Predictors for the Use of Wearable Health Care Devices by US Adults: Insights from a National Survey,” Journal of Medical Internet Research, vol. 22, no. 10. 2020. doi: 10.2196/22443.
[14] “Unpack the STM32MP157x-DK2 board - stm32mpu.” Accessed: Oct. 22, 2023. [Online].
| Available:
https://wiki.st.com/stm32mpu/wiki/Getting_started/STM32MP1_boards/STM32MP157x-DK2/Let%27s_start/Unpack_the_STM32MP157x-DK2_board
[15] “Ks0261 keyestudio AD8232 ECG Measurement Heart Monitor Sensor Module -
Keyestudio | Wiki.” | Accessed: | Oct. | 22, | 2023. | [Online]. | Available:
https://wiki.keyestudio.com/Ks0261_keyestudio_AD8232_ECG_Measurement_Heart_Monitor_Sensor_Module#Test_Result

[16] J. Gordon Betts et al., Anatomy and Physiology 2e. Houston, Texas: OpenStax, 2022.
[17] X. Wang, J. Zhang, C. He, H. Wu, and L. Cheng, “A Novel Emotion Recognition Method Based on the Feature Fusion of Single-Lead EEG and ECG Signals,” IEEE Internet Things J, 2023, doi: 10.1109/JIOT.2023.3320269.
[18] M. Roesler, L. Mohimont, F. Alin, N. Gaveau, and L. A. Steffenel, “Deploying Deep Neural Networks on Edge Devices for Grape Segmentation,” in Communications in Computer and Information Science, 2021. doi: 10.1007/978-3-030-88259-4_3.

## 7. Appendix

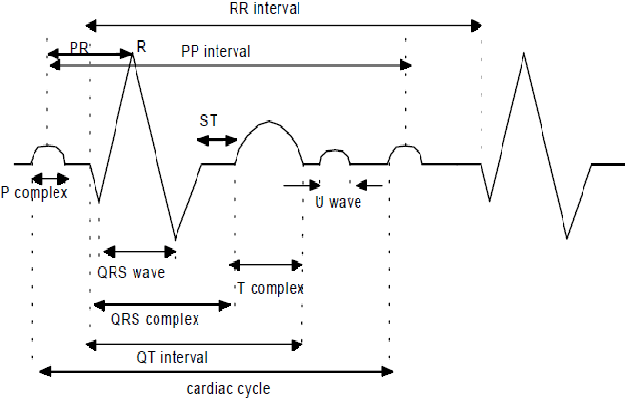
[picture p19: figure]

Figure 1. EEG cycle.


Figure 2. Standard placement of ECG. [16]

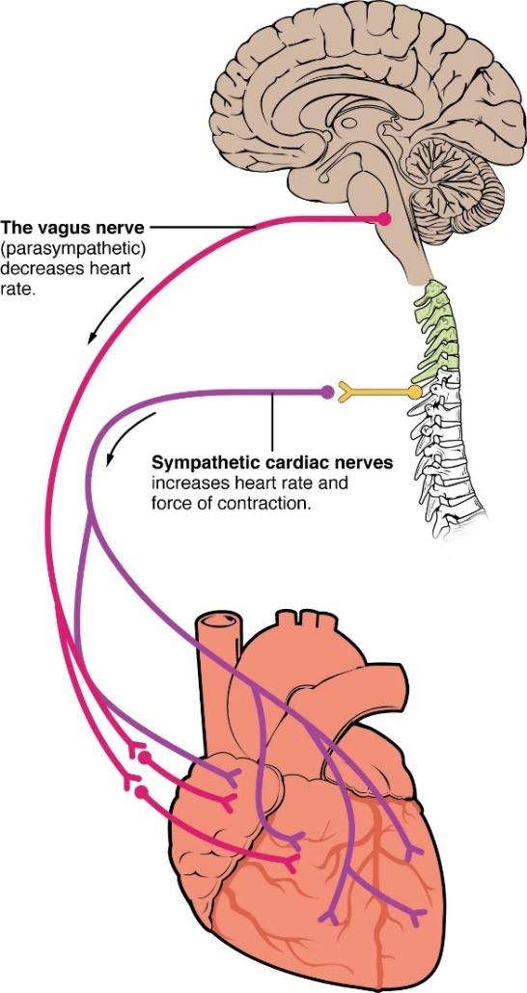
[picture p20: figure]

Figure 3. Autonomic Innervation of the Heart.

Project Specifications

Project Title | Emotion recognition and heart disease detection based on ECG analysis using STM32 MPU.
Project Code | HN-BEng-23-01
Supervisor | Hermawan Nugroho
Moderator | Prof T. Nandha Kumar
Project Description | The perception, cognition, and decision-making processes which people engage daily are significantly influenced by their emotions, which is important for human contact and communication. People's numerous physiological signs behave differently depending on how they are feeling. EEG (electroencephalogram) is a typical biological signal utilized for emotion recognition. However, several studies have shown that accurate emotion recognition using multichannel ECG (electrocardiogram) information is possible [1].

STM32 is a family of microcontrollers created by STMicroelectronics. X-LINUX-AI is an STM32 MPU OpenSTLinux Expansion Package that targets artificial intelligence for STM32MPx series devices. It contains Linux AI frameworks, development tools, as well as applications such as computer vision [2].

In the project, the aim is to explore and develop an edge intelligence system which can run emotion recognition and heart disease detection using ECG data.

References:
[1] X. Wang, J. Zhang, C. He, H. Wu, and L. Cheng, “A Novel Emotion Recognition Method Based on the Feature Fusion of Single-Lead EEG and ECG Signals,” IEEE Internet Things J, 2023, doi: 10.1109/JIOT.2023.3320269.
[2] M. Roesler, L. Mohimont, F. Alin, N. Gaveau, and L. A. Steffenel, “Deploying Deep Neural Networks on Edge Devices for Grape Segmentation,” in Communications in Computer and Information Science, 2021. doi: 10.1007/978-3-030-88259-4_3.
Project Objectives | 1. Explore and improve algorithms for emotion recognition using ECG data. 2. Explore and improve algorithms for heart disease detection using ECG data. 3. Integrate the emotion recognition module (real time analysis) and heart disease detection (offline analysis). 4. Adopt the developed algorithms on STM32 MPU
Project Deliverables | 1. Emotion recognition algorithm using ECG data. 2. Heart disease detection using ECG data. 3. STM32 MPU based edge intelligence system.
Ratio of HW/SW/Resear ch | | HW | SW | Research/Investigation/Des ign
| | 20 | 40 | 40
Lab Space Requirements | ☒ Fixed Space ☐ Ad-hoc Space ☐ Others. Space in the drone-lab
Software (This is software usually supported in the Software Lab) | X-Linux-AI, STM32MX, STM32IDE

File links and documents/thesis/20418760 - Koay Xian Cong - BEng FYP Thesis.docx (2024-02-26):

The University of Nottingham

Faculty of Engineering

Department of Electrical and Electronic Engineering


WellnessAI+: Elevating Mental, Emotional and Physical Health with ECG-Enhanced Artificial Intelligence

AUTHOR : KOAY XIAN CONG

ID : 20418760

SUPERVISOR : DR HERMAWAN NUGROHO

MODERATOR : PROF T. NANDHA KUMAR

DATE : 1 APRIL 2024

Third year project thesis is submitted in partial fulfilment of the requirements of the degree of Bachelor of Engineering

# Acknowledgement

I want to express my heartfelt gratitude to all those who have contributed to the completion of this Final Year Project.

First and foremost, I extend my deepest appreciation towards my supervisor, Dr Hermawan Nugroho, for his invaluable guidance, support, and motivation throughout this entire project. I have received tremendous knowledge and aid from his insightful advice as I carried out the project.

I am also thankful towards my moderator, Prof T. Nandha Kumar for his invaluable feedback and encouragement in ensuring my project is moving in the right direction.

I would also like to extend a word of appreciation towards the Department of Electrical and Electronics Engineering at the University of Nottingham Malaysia, for providing this hands-on opportunity with the necessary knowledge and skills to undertake this project. The project has been enjoyable yet challenging, with each challenge and difficulty presenting opportunities for growth in both technical and intellectual aspects.

I would like to acknowledge the support of my family for their unwavering encouragement and understanding during this academic journey. Their love, encouragement, and belief in my abilities have been a constant source of motivation.

Special thanks go to my friends and classmates for their continuous support, constructive discussions, and words of encouragement, which have helped me overcome challenges and stay focused on my goals.

Thank you all for being part of this journey and for your contributions to this thesis.

# Abstract

# Table of Contents

# 1. Introduction

In this initial segment of the paper, the background, problem statement, proposed solution, objectives, anticipated outcomes, project scope, importance of study and project timeline will be discussed. Additionally, the thesis outline is provided at the end.

## 1.1 Background

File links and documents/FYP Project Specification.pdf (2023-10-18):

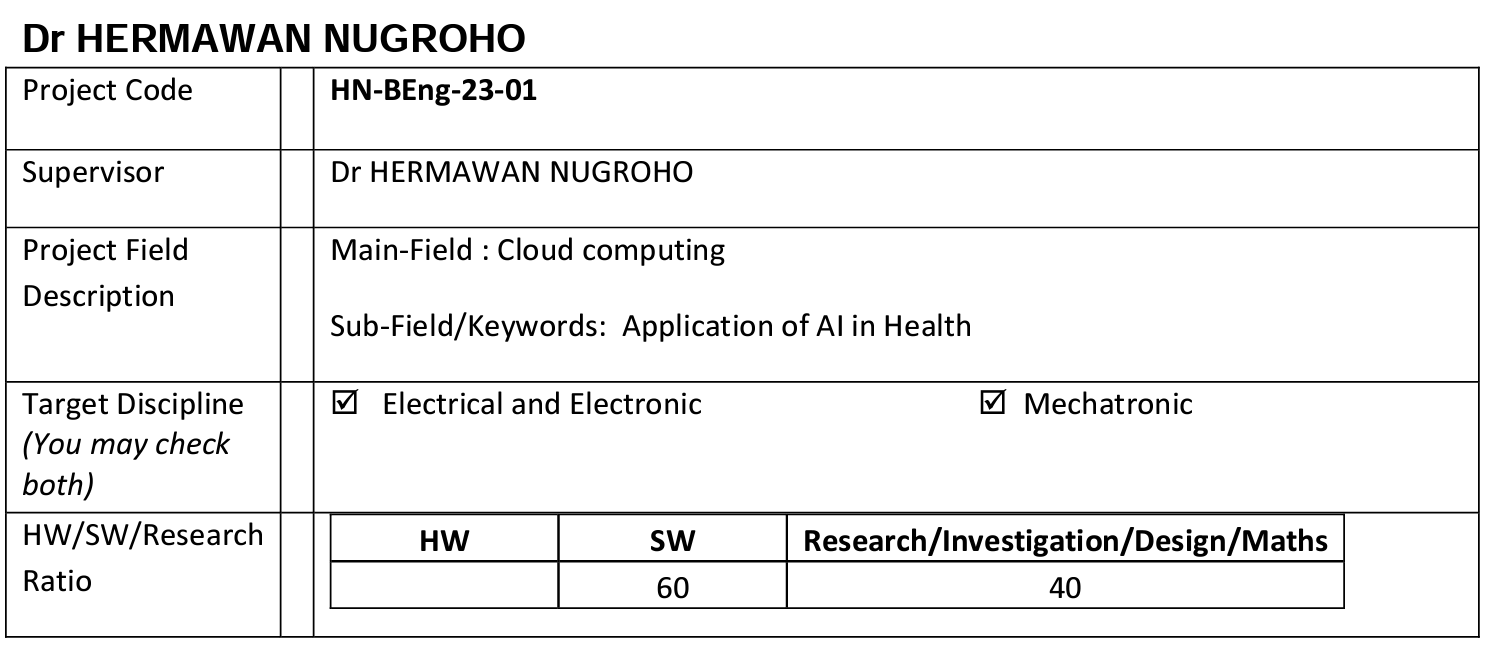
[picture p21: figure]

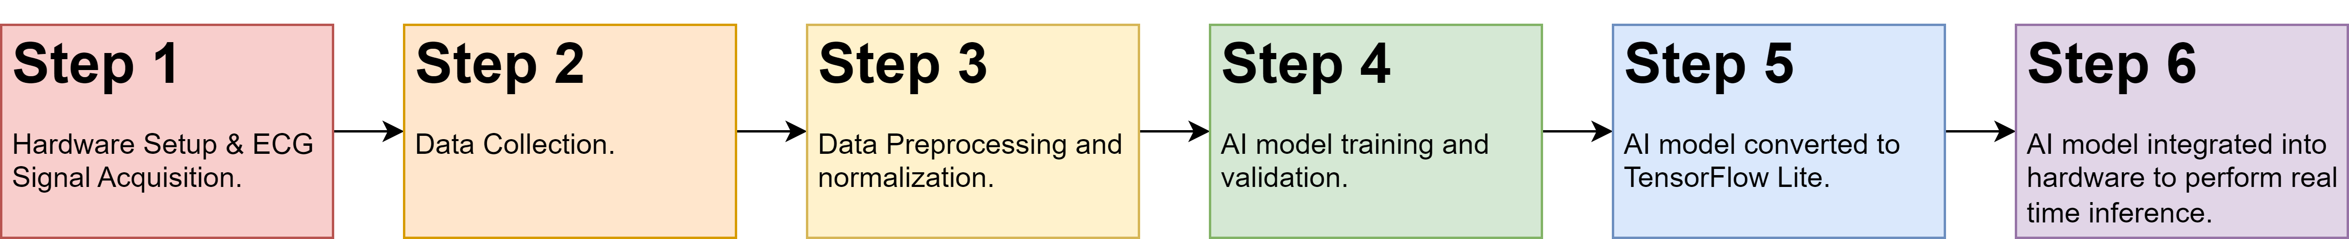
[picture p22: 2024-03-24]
links and documents/thesis/proposed solution horizontal.png

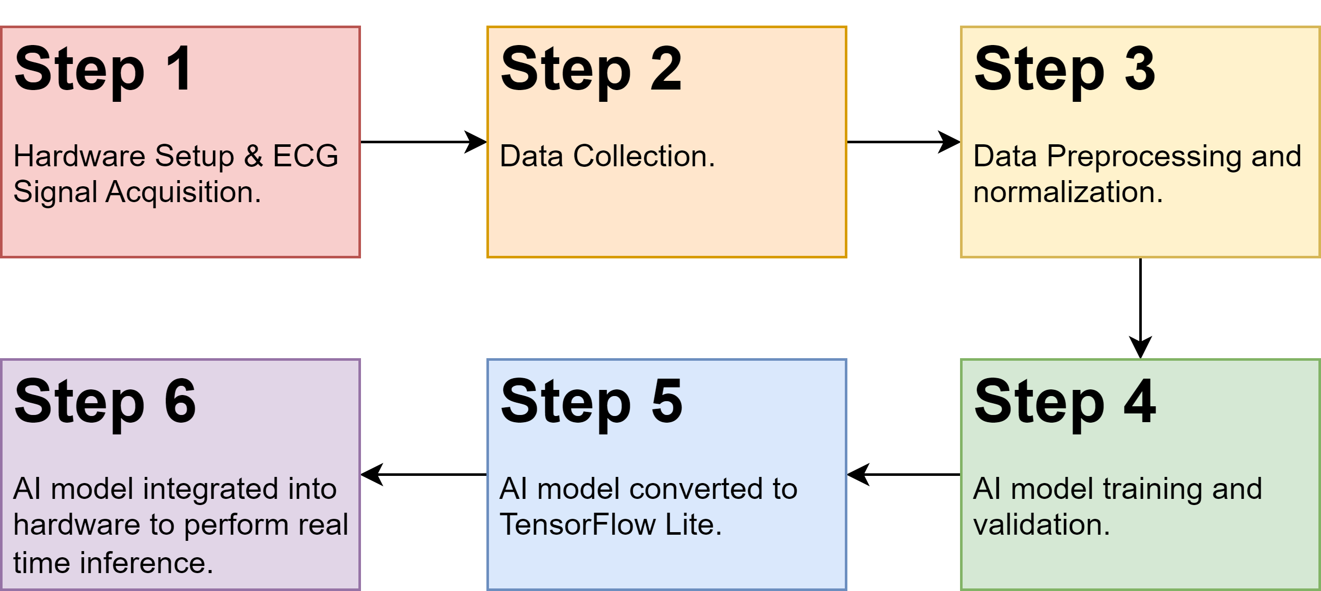
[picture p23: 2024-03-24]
links and documents/thesis/proposed solution colored.png

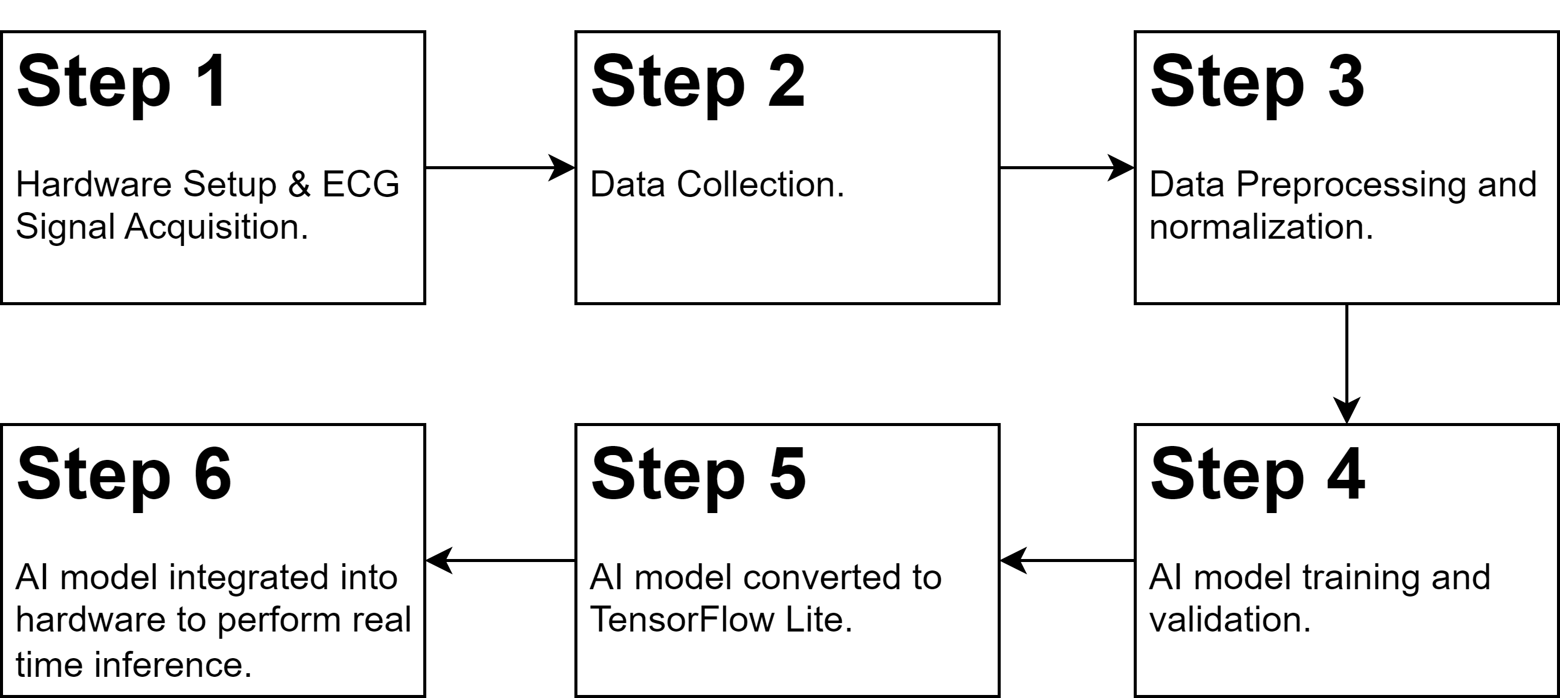
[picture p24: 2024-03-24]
links and documents/thesis/proposed solution.drawio.png

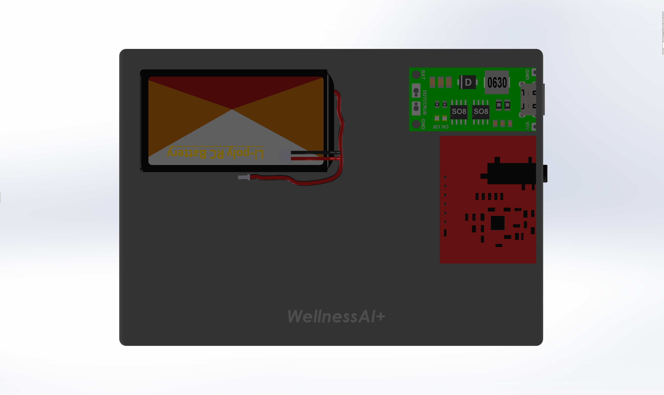
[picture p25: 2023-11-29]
3d model/pic/Inside.png

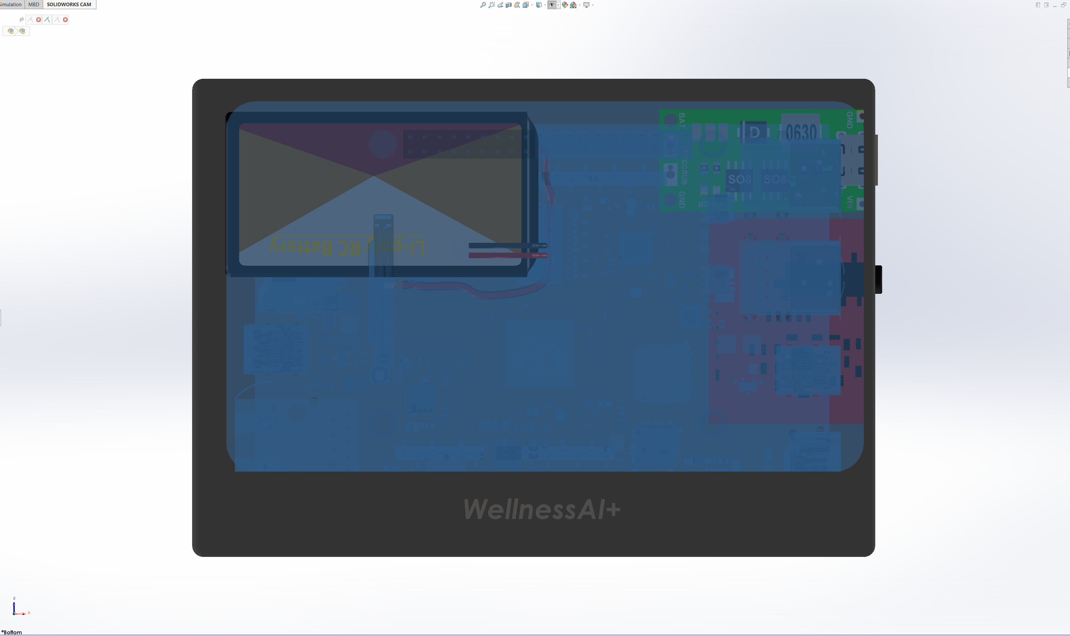
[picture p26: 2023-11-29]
3d model/pic/front+screen+inside.png

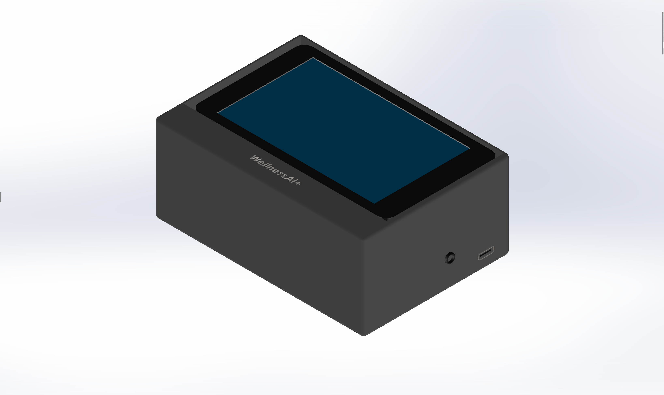
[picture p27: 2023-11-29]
3d model/pic/Side.png

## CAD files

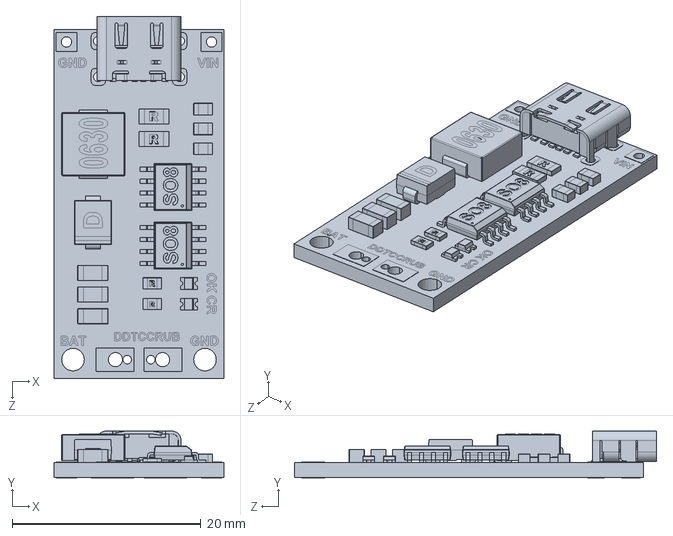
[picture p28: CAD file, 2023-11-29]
3d model/2s-3s-4s-boost-lipo-liion-charger-ddtccrub-1.snapshot.1/DDTCCRUB CN330X.SLDPRT
18.0 x 4.98 x 38.4 mm

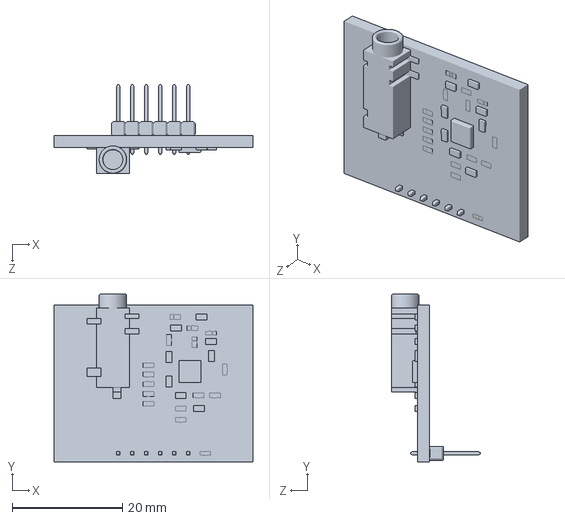
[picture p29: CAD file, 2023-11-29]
3d model/ad8232-module--ecg.SLDPRT
36.1 x 30.5 x 16.1 mm

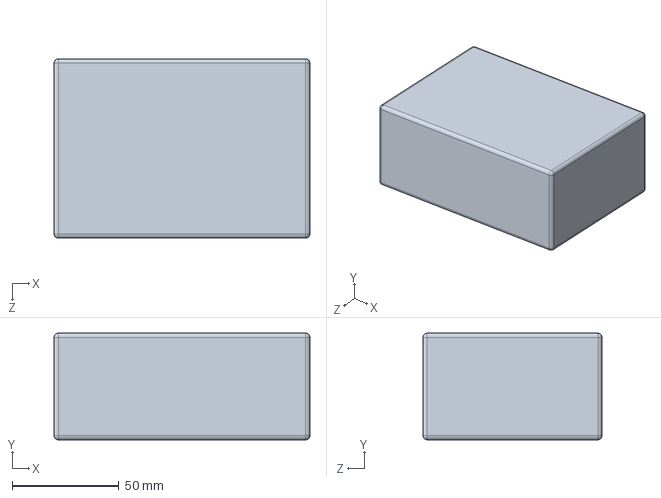
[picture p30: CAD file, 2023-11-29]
3d model/ecg device/box part.SLDPRT
120.0 x 50.0 x 84.0 mm

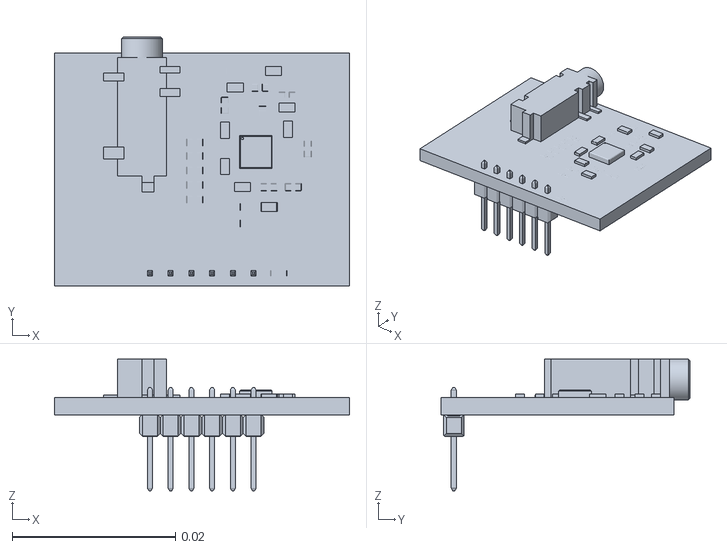
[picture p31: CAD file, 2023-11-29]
3d model/FabConvert.com_ad8232-module--ecg/ad8232-module--ecg.stl
0.0361 x 0.0305 x 0.0161

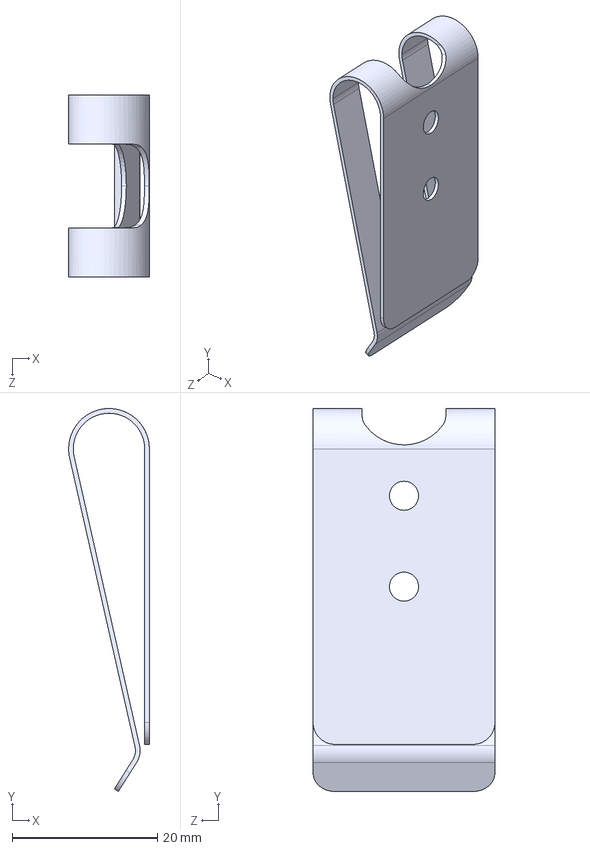
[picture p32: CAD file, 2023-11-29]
3d model/metal-belt-clip-1.snapshot.4/Metal Belt Clip.STEP
11.1 x 52.7 x 25.0 mm

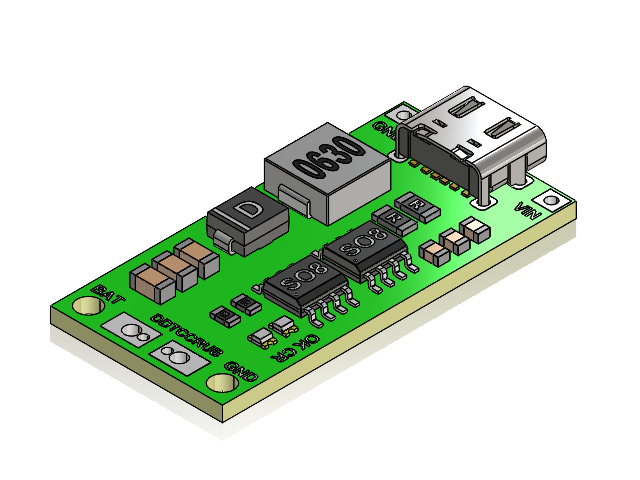
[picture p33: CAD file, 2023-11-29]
3d model/2s-3s-4s-boost-lipo-liion-charger-ddtccrub-1.snapshot.1/DDTCCRUB CN330X_1.SLDASM
Board_DDTCCRUB CN330X_1.STEP
RES_SMD_1206_DDTCCRUB CN330X_1.STEP x 2
CAP_SMD_0805_H0.9_DDTCCRUB CN330X_1.STEP x 3
CAP_SMD_1206_H1.4_DDTCCRUB CN330X_1.STEP x 3
RES_SMD_0805_DDTCCRUB CN330X.STEP x 2
LED_0805_Green_DDTCCRUB CN330X.STEP
LED_0805_Red_DDTCCRUB CN330X_1.STEP
SO8_DDTCCRUB CN330X_1.STEP x 2
Diode_DO214AA(SMB)_DDTCCRUB CN330X_1.STEP
Inductor_SMD_AMPLF_0630_DDTCCRUB CN330X.STEP
USB_Type-C_Female_6pin_DDTCCRUB CN330X_1.STEP

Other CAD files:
3d model/FabConvert.com_ad8232_heart_rate_monitor+v4/ad8232_heart_rate_monitor v4.obj
3d model/lipo-battery-7-4v-900mah-1.snapshot.2/LiPo battery 7.4V 900mAh onshape.sldprt
3d model/ad8232-1.snapshot.1/AD8232_Heart_Rate_Monitor v4.f3d
3d model/ad8232-module--ecg.blend
3d model/lipo-battery-7-4v-900mah-1.snapshot.2/LiPo battery 7.4V 900mAh.ipt
3d model/metal-belt-clip-1.snapshot.4/Metal Belt Clip.SLDPRT

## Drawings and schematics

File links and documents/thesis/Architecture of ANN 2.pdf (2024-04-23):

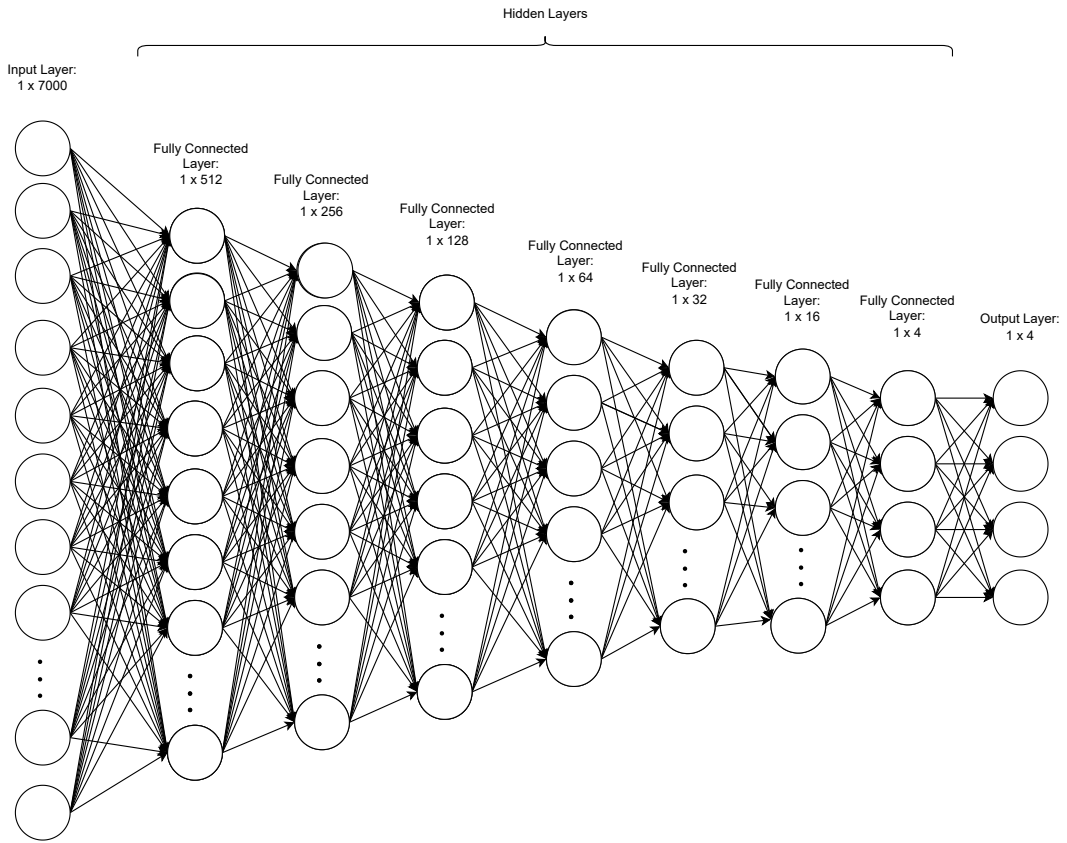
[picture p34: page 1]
Input Layer: 1 x 7000; Fully Connected Layer:; Fully Connected; Layer:; Layer: 1 x 64; Fully Connected Layer: 1 x 32; Fully Connected Layer: 1 x 16; Fully Connected Layer: 1 x 4; Output Layer: 1 x 4; Hidden Layers

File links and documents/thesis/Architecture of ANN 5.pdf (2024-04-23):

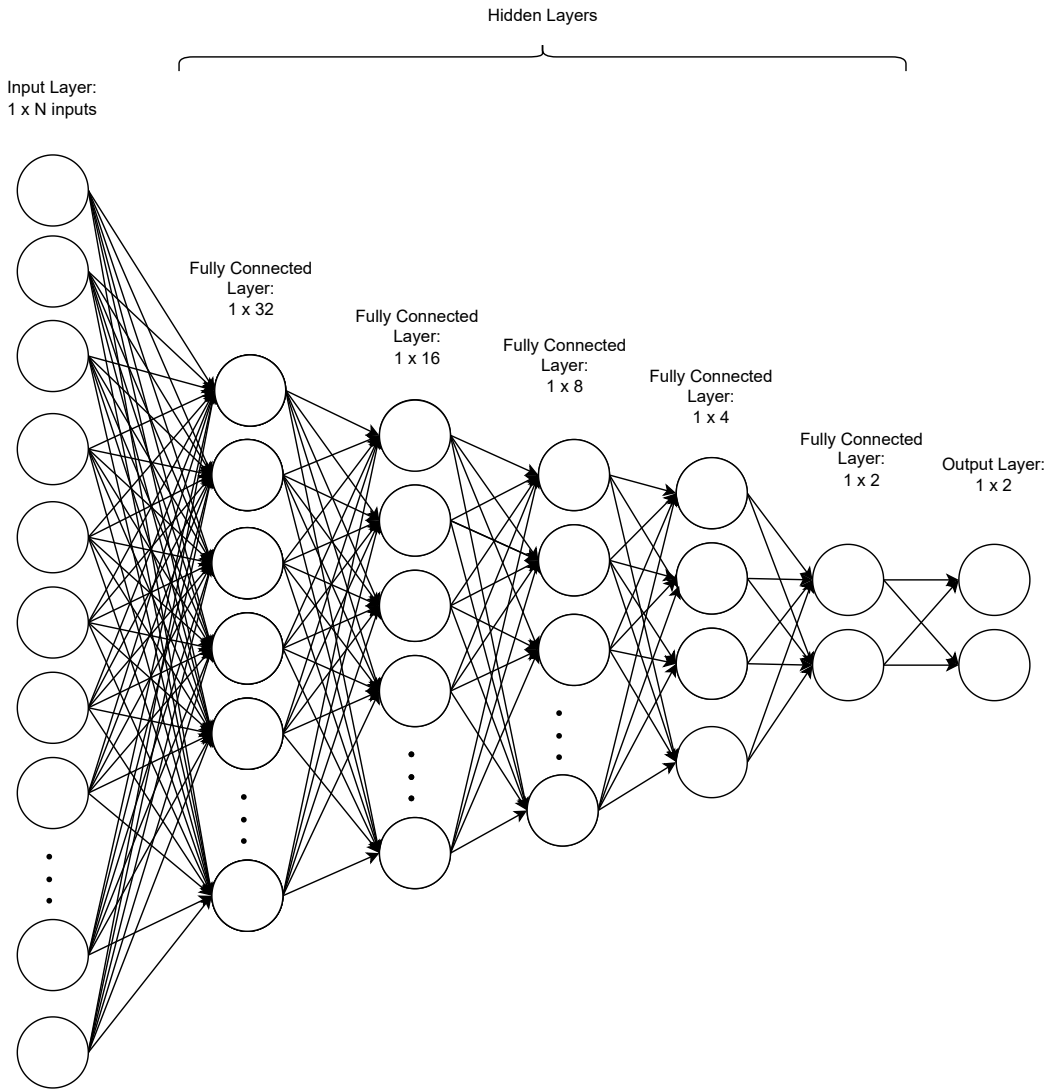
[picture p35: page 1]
Input Layer: 1 x N inputs; Fully Connected Layer:; Fully Connected; Layer: 1 x 16; Layer: 1 x 4; Fully Connected Layer: 1 x 2; Output Layer: 1 x 2; Hidden Layers

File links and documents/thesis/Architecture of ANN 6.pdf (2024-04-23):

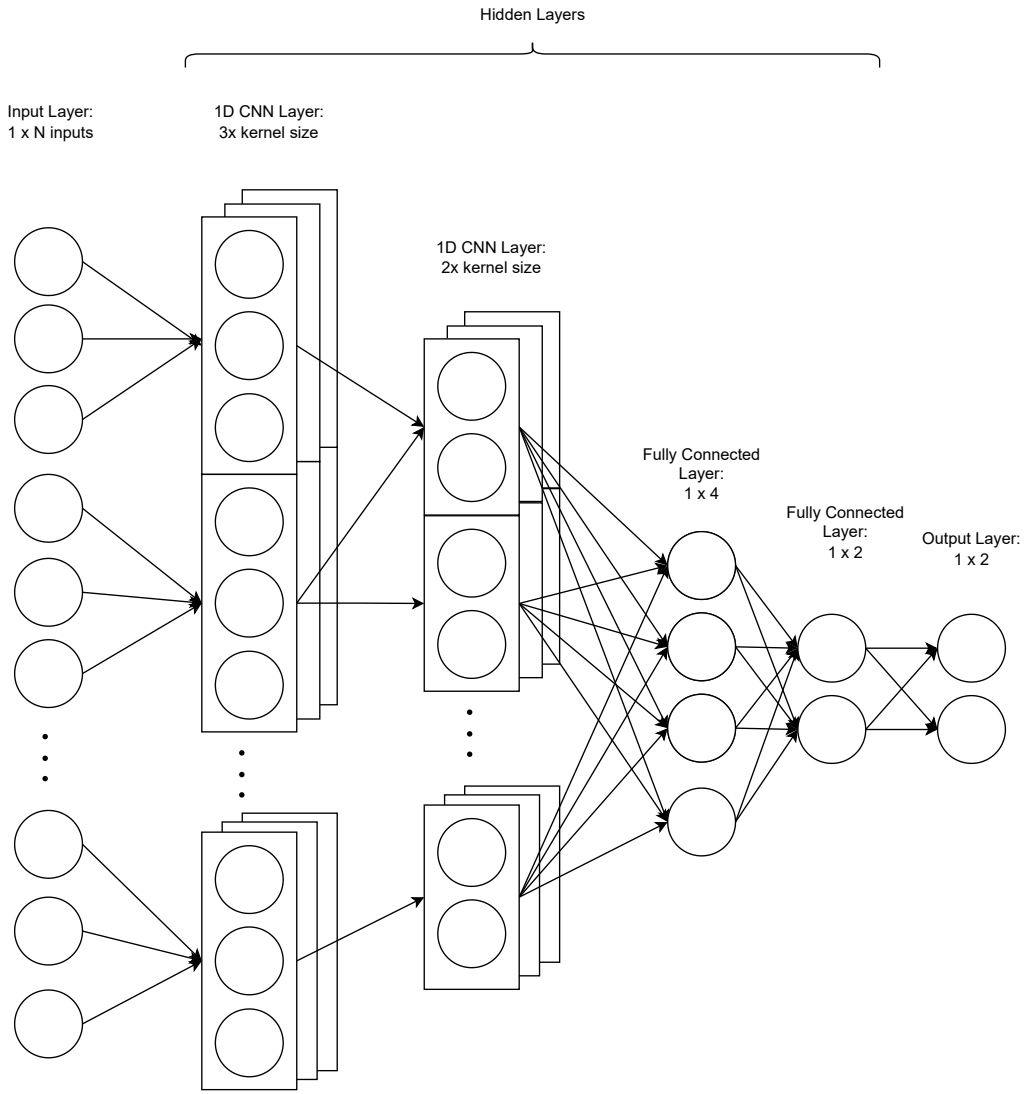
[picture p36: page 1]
Hidden Layers; Input Layer: 1 x N inputs; Fully Connected Layer: 1 x 4; Fully Connected Layer: 1 x 2; Output Layer: 1 x 2; 1D CNN Layer: 3x kernel size; 1D CNN Layer: 2x kernel size

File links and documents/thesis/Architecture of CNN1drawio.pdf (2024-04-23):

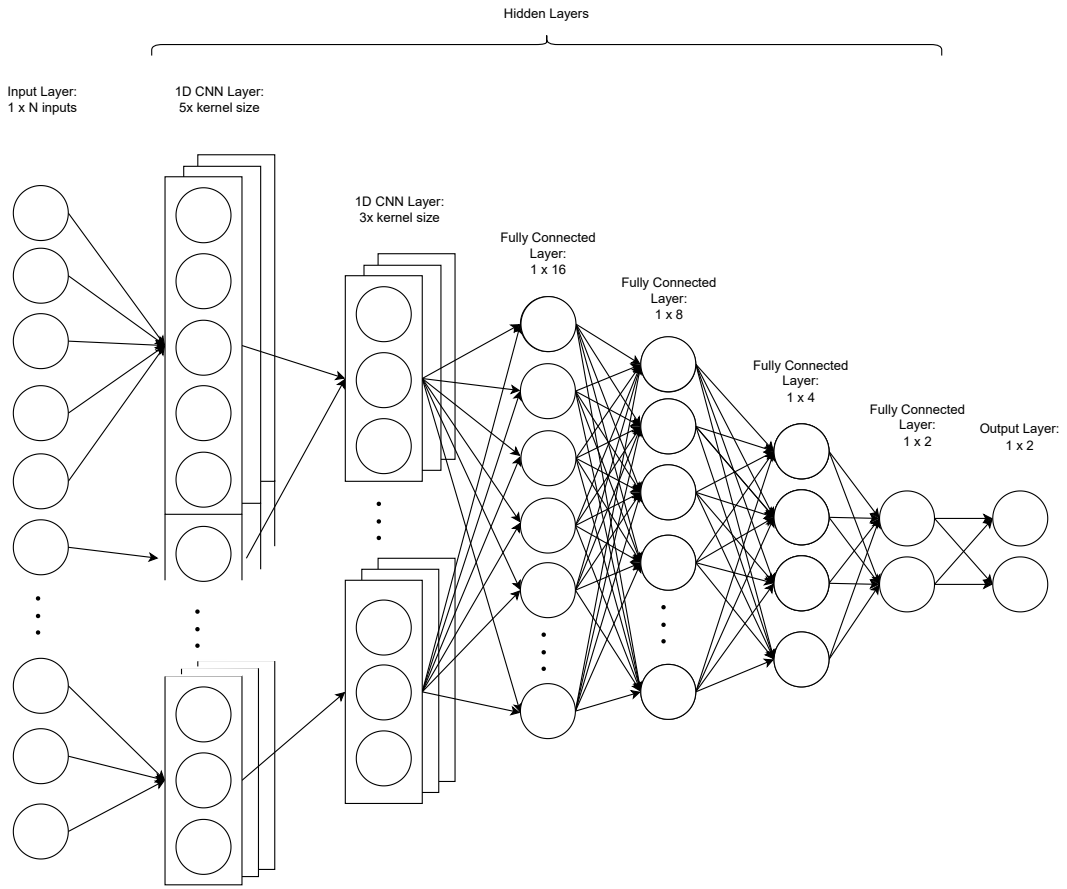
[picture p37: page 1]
Hidden Layers; Input Layer: 1 x N inputs; Fully Connected Layer: 1 x 4; Fully Connected Layer: 1 x 2; Output Layer: 1 x 2; 1D CNN Layer: 5x kernel size; 1D CNN Layer: 3x kernel size; Fully Connected Layer: 1 x 8; Fully Connected Layer: 1 x 16

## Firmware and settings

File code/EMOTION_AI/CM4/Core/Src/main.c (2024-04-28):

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
/* Includes ------------------------------------------------------------------*/
#include "main.h"
#include "openamp.h"

/* USER CODE BEGIN Includes */
#include <stdio.h> // to use sprintf
#include "math.h"
#include "string.h"

#include "ai_platform.h"
#include "emotion_model.h"
#include "emotion_model_data.h"

/* USER CODE END Includes */

ADC_HandleTypeDef hadc2;
DMA_HandleTypeDef hdma_adc2;

CRC_HandleTypeDef hcrc2;

IPCC_HandleTypeDef hipcc;

TIM_HandleTypeDef htim16;

UART_HandleTypeDef huart4;

/* USER CODE BEGIN PV */
ai_handle emotion_model;
float aiInData[AI_EMOTION_MODEL_IN_1_SIZE];
float aiOutData[AI_EMOTION_MODEL_OUT_1_SIZE];
ai_u8 activations[AI_EMOTION_MODEL_DATA_ACTIVATIONS_SIZE];
const char* emotions[AI_EMOTION_MODEL_OUT_1_SIZE] = {
		"non-stress", "stress"
};

ai_buffer * ai_input;
ai_buffer * ai_output;

/* USER CODE END PV */

void SystemClock_Config(void);
void PeriphCommonClock_Config(void);
static void MX_GPIO_Init(void);
static void MX_DMA_Init(void);
static void MX_CRC2_Init(void);
static void MX_UART4_Init(void);
static void MX_ADC2_Init(void);
static void MX_IPCC_Init(void);
static void MX_TIM16_Init(void);
int MX_OPENAMP_Init(int RPMsgRole, rpmsg_ns_bind_cb ns_bind_cb);
/* USER CODE BEGIN PFP */
static void AI_Init(void);
static void AI_Run(float *pIn, float *pOut);
static uint32_t argmax(const float * values, uint32_t len);
/* USER CODE END PFP */

/**
  * @brief  The application entry point.
  * @retval int
  */
int main(void)
{
  /* USER CODE BEGIN 1 */
	char buf[50]; // buffer for serial output string
	int buf_len = 0;
	char msg[100];

	uint32_t timestamp;

  /* USER CODE END 1 */

  /* MCU Configuration--------------------------------------------------------*/

  /* Reset of all peripherals, Initializes the Flash interface and the Systick. */
  HAL_Init();

  if(IS_ENGINEERING_BOOT_MODE())
  {
    /* Configure the system clock */
    SystemClock_Config();
  }

  if(IS_ENGINEERING_BOOT_MODE())
  {
    /* Configure the peripherals common clocks */
    PeriphCommonClock_Config();
  }
  else
  {
    /* IPCC initialisation */
    MX_IPCC_Init();
    /* OpenAmp initialisation ---------------------------------*/
    MX_OPENAMP_Init(RPMSG_REMOTE, NULL);
  }

  /* Initialize all configured peripherals */
  MX_GPIO_Init();
  MX_DMA_Init();
  MX_CRC2_Init();
  MX_UART4_Init();
  MX_ADC2_Init();
  MX_TIM16_Init();
  /* USER CODE BEGIN 2 */
  AI_Init();
  HAL_TIM_Base_Start(&htim16);
  buf_len = sprintf(buf, "\r\n\r\nSTM32 X-Cube-AI test\r\n");
  HAL_UART_Transmit(&huart4, (uint8_t *)buf, buf_len, 100);
  /* USER CODE END 2 */

  /* Infinite loop */
  /* USER CODE BEGIN WHILE */
  while (1)
  {
	  for (int i = 0; i < AI_EMOTION_MODEL_IN_1_SIZE+1; ++i) {
	      HAL_ADC_Start(&hadc2);
	      HAL_ADC_PollForConversion(&hadc2, HAL_MAX_DELAY);
	      aiInData[i] = HAL_ADC_GetValue(&hadc2);
	      sprintf(msg, "%f\r\n", aiInData[i]);
	      HAL_UART_Transmit(&huart4, msg, strlen(msg), HAL_MAX_DELAY);
	      HAL_Delay(1);

	      if (i == AI_EMOTION_MODEL_IN_1_SIZE) {
	    	  timestamp = htim16.Instance->CNT;
	      		  buf_len = sprintf(buf, "Running inference\r\n");
	      		  HAL_UART_Transmit(&huart4, (uint8_t *)buf, buf_len, 100);

	      		  AI_Run(aiInData, aiOutData);
	      		  /* Output results */
	      		  for (uint32_t i = 0; i < AI_EMOTION_MODEL_OUT_1_SIZE; i++) {
	      			  buf_len = sprintf(buf, "Model confidence %d: %8.6f\n", i,aiOutData[i]);
	      			  HAL_UART_Transmit(&huart4, (uint8_t *)buf, buf_len, 100);
	      		  }
	      		if (aiOutData[0] != 0.0 || aiOutData[1] != 1.0) {
	      		      uint32_t class = argmax(aiOutData, AI_EMOTION_MODEL_OUT_1_SIZE);
	      		      buf_len = sprintf(buf, "Prediction : %d - %s\r\nDuration : %lu\r\n", (int)class, emotions[class], htim16.Instance->CNT - timestamp);
	      		      HAL_UART_Transmit(&huart4, (uint8_t *)buf, buf_len, 100);
	      		  }
	      		else {
	      		      buf_len = sprintf(buf, "Sensor Detached\r\n");
	      		      HAL_UART_Transmit(&huart4, (uint8_t *)buf, buf_len, 100);
	      		  }
	      }

	  }
	  // Wait before doing it again
	  HAL_Delay(500);

    /* USER CODE END WHILE */

    /* USER CODE BEGIN 3 */
  }
  /* USER CODE END 3 */
}

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
/* USER CODE BEGIN 4 */

static void AI_Init(void)
{
  ai_error err;

  char buf[50]; // buffer for serial output string
  int buf_len = 0;

  /* Create a local array with the addresses of the activations buffers */
  const ai_handle act_addr[] = { activations };
  /* Create an instance of the model */
  err = ai_emotion_model_create_and_init(&emotion_model, act_addr, NULL);
  if (err.type != AI_ERROR_NONE) {
	  buf_len = sprintf(buf, "ai_emotion_model_create error - type=%d code=%d\r\n", err.type, err.code);
	  HAL_UART_Transmit(&huart4, (uint8_t *)buf, buf_len, 100);
//	  printf("ai_emotion_model_create error - type=%d code=%d\r\n", err.type, err.code);
	  Error_Handler();
  }
  ai_input = ai_emotion_model_inputs_get(emotion_model, NULL);
  ai_output = ai_emotion_model_outputs_get(emotion_model, NULL);
}

static void AI_Run(float *pIn, float *pOut)
{

  ai_i32 batch;
  ai_error err;

  char buf[50]; // buffer for serial output string
  int buf_len = 0;

  /* Update IO handlers with the data payload */
  ai_input[0].data = AI_HANDLE_PTR(pIn);
  ai_output[0].data = AI_HANDLE_PTR(pOut);

  batch = ai_emotion_model_run(emotion_model, ai_input, ai_output);
  if (batch != 1) {
    err = ai_emotion_model_get_error(emotion_model);
    buf_len = sprintf(buf, "AI ai_emotion_model_run error - type=%d code=%d\r\n", err.type, err.code);
    HAL_UART_Transmit(&huart4, (uint8_t *)buf, buf_len, 100);
    //printf("AI ai_emotion_model_run error - type=%d code=%d\r\n", err.type, err.code);
    Error_Handler();
  }
}

static uint32_t argmax(const float * values, uint32_t len)
{
  float max_value = values[0];
  uint32_t max_index = 0;
  for (uint32_t i = 1; i < len; i++) {
    if (values[i] > max_value) {
      max_value = values[i];
      max_index = i;
    }
  }
  return max_index;
}

void HAL_ADC_ConvHalfCpltCallback(ADC_HandleTypeDef* hadc) {
//	HAL_GPIO_WritePin(LD2_GPIO_Port, LD2_Pin, GPIO_PIN_SET);
}

void HAL_ADC_ConvCpltCallback(ADC_HandleTypeDef* hadc) {
//	HAL_GPIO_WritePin(LD2_GPIO_Port, LD2_Pin, GPIO_PIN_RESET);
}
/* USER CODE END 4 */
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


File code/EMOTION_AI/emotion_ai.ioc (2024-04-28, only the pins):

Mcu.UserName=STM32MP157FACx
PA0.Signal=PWR_WKUP1
PA1.GPIO_Label=ETH_RX_CLK [RTL8211F_RXCLK_PHYAD1]
PA1.Signal=ETH1_RX_CLK
PA10.GPIO_Label=HDMI_NRST [SiI9022ACNU_RESET\#]
PA10.Signal=GPIO_Output
PA13.GPIO_Label=PA13 [LD6_RED]
PA13.Signal=GPIO_Output
PA14.GPIO_Label=PA14 [SW-PUSH-TS-02H-Blue]
PA14.Signal=GPIO_Input
PA15.GPIO_Label=BL_CTRL [STLD40DPUR_EN]
PA15.Signal=GPIO_Output
PA2.GPIO_Label=ETH_MIO [RTL8211F_MIO]
PA2.Signal=ETH1_MDIO
PA4.GPIO_Label=USB_PWR_CC1[317JD24BZTF3K3C3_CC1]
PA4.Signal=ADCx_INP18
PA5.GPIO_Label=USB_PWR_CC2[317JD24BZTF3K3C3_CC2]
PA5.Signal=ADCx_INP19
PA6.GPIO_Label=ETH_MDINT [RTL8211F_INT]
PA6.Signal=GPIO_Input
PA7.GPIO_Label=ETH_RX_DV [RTL8211F_RXCTL_PHYAD2]
PA7.Signal=ETH1_RX_CTL
PA9.Signal=I2S2_CK
PB0.GPIO_Label=ETH_RXD2 [RTL8211F_RXD2_PLLOFF]
PB0.Signal=ETH1_RXD2
PB1.GPIO_Label=ETH_RXD3 [RTL8211F_RXD3_PHYAD0]
PB1.Signal=ETH1_RXD3
PB11.GPIO_Label=ETH_TX_EN [RTL8211F_TXCTL]
PB11.Signal=ETH1_TX_CTL
PB14.GPIO_Label=SDMMC2_D0 [LBEE5KL1DX_SDIO_D0]
PB14.Signal=SDMMC2_D0
PB15.GPIO_Label=SDMMC2_D1 [LBEE5KL1DX_SDIO_D1]
PB15.Signal=SDMMC2_D1
PB2.GPIO_Label=STLINK_TX [STM32F103CBT6_PA2]
PB2.Signal=UART4_RX
PB3.GPIO_Label=SDMMC2_D2 [LBEE5KL1DX_SDIO_D2]
PB3.Signal=SDMMC2_D2
PB4.GPIO_Label=SDMMC2_D3 [LBEE5KL1DX_SDIO_D3]
PB4.Signal=SDMMC2_D3
PB6.GPIO_Label=HDMI_CEC [SiI9022ACNU_CEC_D]
PB6.Signal=CEC
PB7.GPIO_Label=uSD_DETECT [PJS008-2003-1]
PB7.Signal=GPIO_Input
PB9.Signal=I2S2_WS
PC1.GPIO_Label=ETH_MDC [RTL8211F_MDC]
PC1.Signal=ETH1_MDC
PC10.GPIO_Label=SDMMC1_D2 [PJS008-2003-1]
PC10.Signal=SDMMC1_D2
PC11.GPIO_Label=SDMMC1_D3 [PJS008-2003-1]
PC11.Signal=SDMMC1_D3
PC12.GPIO_Label=SDMMC1_CK [PJS008-2003-1]
PC12.Signal=SDMMC1_CK
PC13.GPIO_Label=PMIC_WAKEUP [STPMU1A_WAKEUP]
PC13.Signal=GPIO_Output
PC14-OSC32_IN.Signal=RCC_OSC32_IN
PC15-OSC32_OUT.Signal=RCC_OSC32_OUT
PC2.GPIO_Label=ETH_TXD2 [RTL8211F_TXD2]
PC2.Signal=ETH1_TXD2
PC4.GPIO_Label=ETH_RXD0 [RTL8211F_RXD0_RXDLY]
PC4.Signal=ETH1_RXD0
PC5.GPIO_Label=ETH_RXD1 [RTL8211F_RXD1_TXDLY]
PC5.Signal=ETH1_RXD1
PC6.GPIO_Label=TE  [FH26W-25S_TE]
PC6.Signal=GPIO_Output
PC8.GPIO_Label=SDMMC1_D0 [PJS008-2003-1]
PC8.Signal=SDMMC1_D0
PC9.GPIO_Label=SDMMC1_D1 [PJS008-2003-1]
PC9.Signal=SDMMC1_D1
PD0.GPIO_Label=WL_HOST_WAKE [LBEE5KL1DX_WL_HOST_WAKE]
PD0.Signal=GPIO_Input
PD11.GPIO_Label=LED_B [LD8_BLUE]
PD11.Signal=GPIO_Output
PD12.GPIO_Label=I2C1_SCL [CS42L51-CNZ_SCL]
PD12.Signal=I2C1_SCL
PD2.GPIO_Label=SDMMC1_CMD [PJS008-2003-1]
PD2.Signal=SDMMC1_CMD
PD3.GPIO_Label=USART2_CTS [LBEE5KL1DX_BT_UART_CTS_N]
PD3.Signal=USART2_CTS
PD4.GPIO_Label=USART2_RTS [LBEE5KL1DX_BT_UART_RTS_N]
PD4.Signal=USART2_RTS
PD5.GPIO_Label=USART2_TX [LBEE5KL1DX_BT_UART_TX]
PD5.Signal=USART2_TX
PD6.GPIO_Label=USART2_RX [LBEE5KL1DX_BT_UART_RX]
PD6.Signal=USART2_RX
PE0.Signal=SAI2_MCLK_A
PE11.Signal=GPIO_Input
PE14.Signal=GPIO_Input
PE2.GPIO_Label=ETH_TXD3 [RTL8211F_TXD3]
PE2.Signal=ETH1_TXD3
PE3.GPIO_Label=SDMMC2_CK [LBEE5KL1DX_SDIO_CK]
PE3.Signal=SDMMC2_CK
PE4.GPIO_Label=RSTN  [FH26W-25S_RSTN]
PE4.Signal=GPIO_Output
PF11.Signal=SAI2_SD_B
PF14.Signal=SharedAnalog_PF14
PF15.GPIO_Label=I2C1_SDA [CS42L51-CNZ_SDA]
PF15.Signal=I2C1_SDA
PF2.GPIO_Label=INT [FH26W-25S_INT]
PF2.Signal=GPIO_Input
PG1.GPIO_Label=HDMI_INT [SiI9022ACNU_INT]
PG1.Signal=GPIO_Input
PG11.GPIO_Label=STLINK_RX [STM32F103CBT6_PA3]
PG11.Signal=UART4_TX
PG13.GPIO_Label=ETH_TXD0 [RTL8211F_TXD0]
PG13.Signal=ETH1_TXD0
PG14.GPIO_Label=ETH_TXD1 [RTL8211F_TXD1]
PG14.Signal=ETH1_TXD1
PG4.GPIO_Label=ETH_GTX_CLK [RTL8211F_TXCLK]
PG4.Signal=ETH1_GTX_CLK
PG5.GPIO_Label=ETH_CLK125 [RTL8211F_CLKOUT]
PG5.Signal=ETH1_CLK125
PG6.GPIO_Label=SDMMC2_CMD [LBEE5KL1DX_SDIO_CMD]
PG6.Signal=SDMMC2_CMD
PG9.GPIO_Label=AUDIO_RST [CS42L51-CNZ_RESET]
PG9.Signal=GPIO_Output
PH0-OSC_IN.Signal=RCC_OSC_IN
PH1-OSC_OUT.Signal=RCC_OSC_OUT
PH4.GPIO_Label=WL_REG_ON [LBEE5KL1DX_WL_REG_ON]
PH4.Signal=GPIO_Output
PH5.GPIO_Label=BT_HOST_WAKE [LBEE5KL1DX_BT_HOST_WAKE]
PH5.Signal=GPIO_Input
PH7.GPIO_Label=LED_Y [LD7_ORANGE]
PH7.Signal=GPIO_Output
PI11.GPIO_Label=STUSB1600_IRQOUTn [STUSB1600_ALERT\#]
PI11.Signal=GPIO_Input
PI3.Signal=I2S2_SDO
PI5.Signal=SAI2_SCK_A
PI6.Signal=SAI2_SD_A
PI7.Signal=SAI2_FS_A
PI8.Signal=RTC_LSCO

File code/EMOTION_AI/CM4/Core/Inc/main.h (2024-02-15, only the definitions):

#define USB_PWR_CC2_Pin GPIO_PIN_5
#define USB_PWR_CC2_GPIO_Port GPIOA
#define USB_PWR_CC1_Pin GPIO_PIN_4
#define USB_PWR_CC1_GPIO_Port GPIOA
#define STLINK_RX_Pin GPIO_PIN_11
#define STLINK_RX_GPIO_Port GPIOG
#define STLINK_TX_Pin GPIO_PIN_2
#define STLINK_TX_GPIO_Port GPIOB

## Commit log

2023-10-18 update progress
    [Gantt Chart.xlsx]
2023-10-23 created gantt chart
    [Gantt Chart.xlsx]
2023-10-23 update file location
    [Gantt Chart.xlsx]
2023-11-20 update (done adc uart)
2023-11-20 update uart adc success!
2023-11-29 design wearable
    [AD8232_Heart_Rate_Monitor v4.f3d, DDTCCRUB CN330X.SLDPRT, DDTCCRUB CN330X_1.SLDASM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]
2024-02-15 init commit, no bug
    [main.c]
2024-02-15 emotion classification done
    [emotion_ai_CM4.cfg]
2024-03-04 init commit sensor connection image
2024-03-18 Fit model in ARM Cortex-M
2024-03-25 added time inference and sensor detection
2024-04-09 print inference
2024-04-09 update serial printout
2024-04-11 update bugs "sensor detached"
    [app.py]

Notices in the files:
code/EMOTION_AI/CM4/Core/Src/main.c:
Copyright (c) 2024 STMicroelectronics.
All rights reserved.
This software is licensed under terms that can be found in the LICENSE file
